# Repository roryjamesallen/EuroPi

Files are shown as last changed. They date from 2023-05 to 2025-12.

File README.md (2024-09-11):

# EuroPi

The EuroPi is a fully user reprogrammable module based on the [Raspberry Pi Pico](https://www.raspberrypi.com/products/raspberry-pi-pico/), which allows users to process inputs and controls to produce outputs based on code written in Python. The entire project is open-source.

<p>
  <a href="https://discord.gg/JaQwtCnBV5">
        chat on Discord
  </a>
  <a href="https://www.reddit.com/r/EuroPi/">
        
  </a>
  <a href="https://github.com/Allen-Synthesis/EuroPi/tree/main/software/contrib">
        
  </a>
  <a href="https://github.com/Allen-Synthesis/EuroPi/releases/">
        
  </a>

</p>

---

This repository relates to the EuroPi module, however some users may be expecting to see what is now referred to as the 'EuroPi Prototype'. The repository for this (now deprecated) module [can be found here](https://github.com/roryjamesallen/EuroPi-Prototype)

You can find more about this and other projects of mine on [my website](https://www.allensynthesis.co.uk)

github banner

## Capabilities

* 6 0-10V Control Voltage outputs, each with indicator LED
* 2 Knobs with 12 bit resolution
* 2 Push Buttons
* 1 0-12V Control Voltage input with 12 bit resolution
* 1 Digital input for external clocking or gate sources
* 128x32 OLED Display
* I²C expansion header on the rear for extra sensors or outputs

### Improvements on the Prototype version

* All outputs are the full Eurorack unipolar range of 0-10V, previously only 0-3.3V
* Two inputs, previously no way to accept input from other modules
* The buttons have hardware debouncing to allow users to change out capacitor values for reduced accidental 'double click'
* A 10 pin Eurorack shrouded power header is now used to prevent accidental reverse powering of the module
* The 5V supply for the Pico is now regulated down from the +12V supply, so no 5V rail is required from your Eurorack power supply
* The power supply is now diode protected to prevent back-powering your rack when the module is connected via USB
* All jacks are protected from overvoltage input (previously the Pico GPIO pin was directly exposed to any input, potentially leading to damage)

### Documentation

**Hardware**: Details of the hardware can be found at [hardware README](hardware/EuroPi/README.md). Additionally the [BoM](hardware/EuroPi/bill_of_materials.md) and the [build guide](hardware/EuroPi/build_guide.md) can be found in the hardware folder.

**Software**: Before using any of the software, follow the instructions in [programming_instructions.md](software/programming_instructions.md) to set up and calibrate your module.

A list of user contributed scripts and their usage can be found in [contrib/README.md](software/contrib/README.md).
There is also a [YouTube playlist](https://www.youtube.com/playlist?list=PLbingtr9KGPUdIODLWgzgAdIyN497YyEs) showcasing EuroPi and some of the different scripts available.

The EuroPi firmware API documentation can be found at https://allen-synthesis.github.io/EuroPi/. This documentation will explain all of the available features of the EuroPi firmware API. It also includes some examples of how to use various features of the firmware as well as [interesting_things.md](software/interesting_things.md).

If you would like to extend any of the features of the EuroPi software, you can view the firmware source code at [europi.py](software/firmware/europi.py).

### Issues
If you find any bugs, either in the software, the hardware, or the documentation, please create an Issue by clicking the 'Issue' tab along the top.
Please feel free to create any issue you see fit, I'll either attempt to fix it or explain it.
There are Issue templates available, so please choose whichever is most relevant, depending on if your Issue is a hardware or software bug, if it's a documentation error or suggestion, if it's a question about the project as a whole, or a suggestion about the project as a whole.

### License

This module, and any documentation included in this repository, is entirely "free" software and hardware, under different licenses depending on the software, hardware, and documentation itself.

* Software: [Apache 2.0](software/LICENSE)
* Hardware: [CERN OHL-S v2](hardware/LICENSE)
* Documentation: [CC0 1.0](LICENSE)

Anyone is welcome to design their own versions of the idea, or modify my designs.
The only thing I would ask is that you refrain from using the brand name 'Allen Synthesis' on your DIY builds if they have modified my files in any way, just to prevent any confusion if they end up being re-sold or distributed. This is in line with section 8.2 of the CERN license. You may use the brand name if you have simply copied the files from this repository to replicate without modification.

If you have a bug fix or improvement that you think is worth sharing, then feel free to send over any pictures or documentation and it can be merged with the main project!

### Disclaimer

Recreate any of the files found in this repository at your own risk; I will attempt to solve any issues that you might have with my designs, but I can't guarantee that there are not minor bugs in any of the documents, both hardware and software.

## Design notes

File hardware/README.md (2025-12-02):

# Hardware Overview
There are multiple versions of the hardware documented in this directory, the original EuroPi (through-hole), the new EuroPi-SMD (surface-mount), and a stripboard version (stripboard). Each has a different build guide and bill of materials, so make sure you follow the one you want to build.

The surface-mount version is the simplest to DIY as you only need to solder on the components which stick through the panel, i.e. the jacks, knobs etc. All of the other circuitry is soldered onto the PCB already.

The through-hole version is slightly more in depth as you need to solder on every component, however only through-hole components are used, so this isn't as hard as it sounds. This is the build most people have made and was previously the only publicly available build at all.

The stripboard version is a much rougher layout and does not use a PCB at all, but instead uses 'stripboard'. This hasn't been tested nearly as much as the other two, but people have successfully built it and shared their version on Discord.

# Hardware Specifications
All hardware variants share the same specifications as the components and schematics are the same.

## Outputs
- 1k Output Impedance
- RC filter smoothed PWM
- ~1.5kHz Maximum usable frequency (without changing RC values)
- 0.000176V Maximum ripple peak-to-peak
- 0.0108s Settle time from 0% to 90% duty cycle
- 0-10V

## Analogue Input
- 100k Input Impedance
- 0-12V Readable Range
- Protected for ±36V (TL074 limits, MCP6002 will always clip to ±3.3V)

## Digital Input
- 100k Input Impedance
- 0.8V threshold to read as high

## OLED
- SSD1306 0.91"
- 128 x 32 pixels
- I2C Protocol

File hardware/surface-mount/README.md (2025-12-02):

# EuroPi (surface-mount)

This is a version of the EuroPi that has all of the components other than the Pico, power header, and panel components pre-soldered using SMD packages. This makes for a much simpler DIY build, as well as a thinner end result. It has identical technical specifications to the through-hole version except for also supporting input detection.

The board files for this version are designed in [KiCad](https://www.kicad.org/) so are a more friendly starting point for third-party development or modification.

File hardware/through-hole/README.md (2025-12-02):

# EuroPi (through-hole)
This directory contains the build instructions and production files for the 'original' EuroPi, which is the entirely through-hole build. This is the build the majority of users have.

# PCB Files

The PCB files are in two file types:
- .pcb files, which can be opened in [DesignSpark](https://www.rs-online.com/designspark/pcb-software) free PCB software
- .rar files, which are zipped folders containing the Gerber format PCBs. Each entire .rar folder can be dragged and dropped to a PCB manufacturer such as [JLC PCB](https://jlcpcb.com/) (my personal choice)

There are two different options for the panel PCB:
- Panel, which is made for JLC aluminium production
- Black Panel, which is made for FR4 production by any manufacturer
The subtleties of these files are minor, but JLC will only produce the aluminium boards correctly if the layers are in the order that they are in these files, which is silkscreen on the bottom layer and copper on the top.

In line with the license used for the PCBs, if you modify these files before production (rather than just dragging and dropping the gerber files), please contact me if you would like to keep the 'Allen Synthesis' name on it! This is not based in any mistrust of your modifications, but in the risk that someone else might then get hold of these boards or files, turn to me for support, and be disappointed.

If you would rather save yourself the effort of ordering boards (and potentially paying import charges), you can also order Panel + PCB kits directly from me, which will ship with a lower lead time than a PCB manufacturer too!
https://allensynthesis.square.site/

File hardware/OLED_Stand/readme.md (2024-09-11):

# 3D printed OLED stands

A simple small stand for your OLED display. This helps hold it in place while soldering and keeps it snug against the face of the module.

> There are two versions of the stand, one for the CPC style OLED and one for the TPH (the Pi Hut) style OLED.

## CPC style OLED

3D print the file [OLED_Stand.stl](OLED_Stand.stl).

Put the stand on something about 5-10mm tall, then solder some component cutoff wire to your OLED so that they fall below the bottom of the stand. Place on your interface board, solder pins to board. Pins may need to be bent slightly for the model of OLED that you're using. Just align the stand and the display and you should be right in the middle of the cutout.

Print upside down for best results/least amount of supports. Should print very quickly on most printers. It takes 30 minutes on an Ender3 Pro.

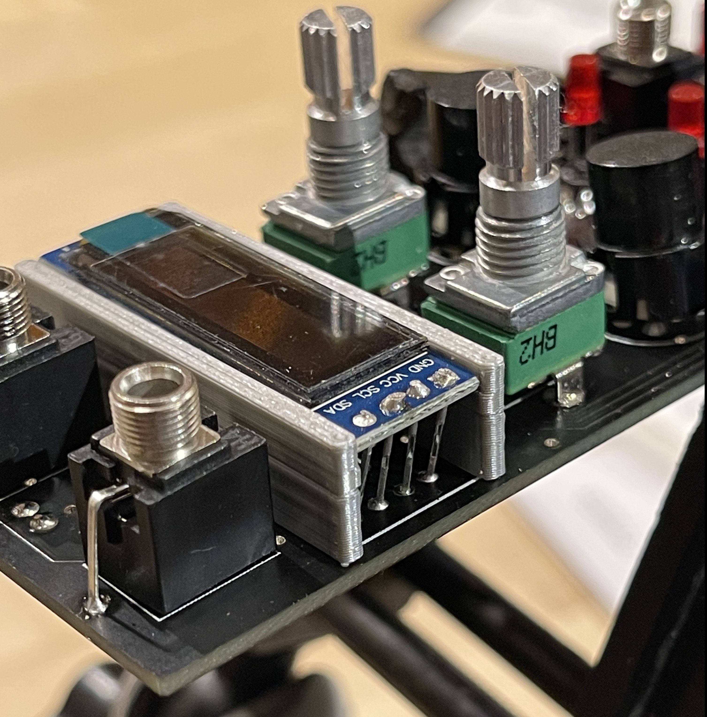
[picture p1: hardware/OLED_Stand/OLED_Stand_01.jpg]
OLED Stand
 

## TPH (the Pi Hut) style OLED

3D print the file [OLED_Stand_Pi_Hut.stl](OLED_Stand_Pi_Hut.stl).

The TPH (the Pi Hut) OLED needs a different stand because it has a chunky connector on the side (unused by the EuroPi).

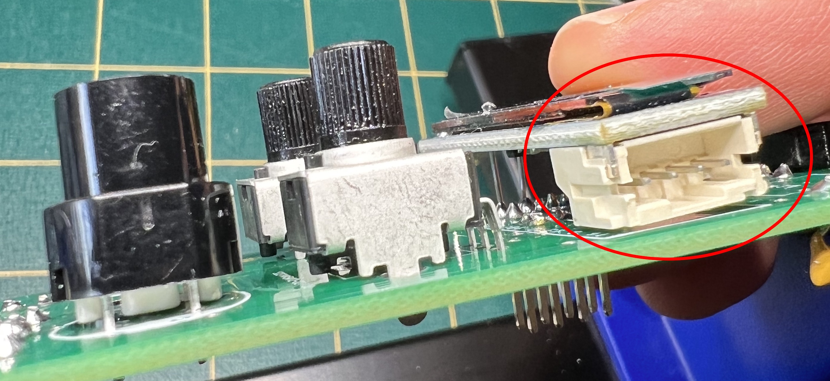
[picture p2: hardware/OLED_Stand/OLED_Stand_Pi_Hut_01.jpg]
OLED Pi Hut style
 

- Slide your OLED into the groove.
- Place the stand with OLED into position on the PCB (hold in place using bluetack).
- Solder the four vertical wires.

The stand has a notch to avoid certain soldering points. You should keep the stand permanently in your EuroPi for added stability of the screen.

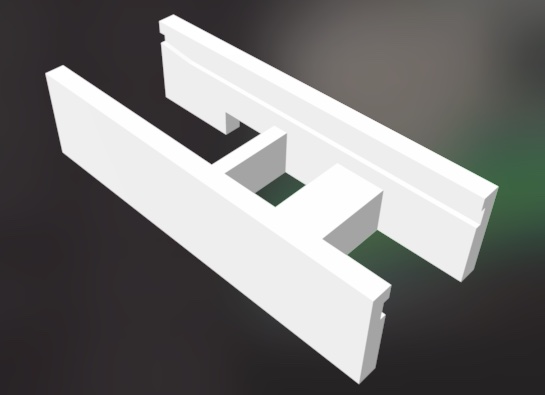
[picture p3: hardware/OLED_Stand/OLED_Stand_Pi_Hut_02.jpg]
OLED Stand for Pi Hut style


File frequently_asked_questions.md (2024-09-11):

# FAQ

### Frequently asked questions about the EuroPi project. If you can't find the answer to your question here, head over to [The Discord](https://discord.gg/JaQwtCnBV5) and ask it in the support channel!

#

### Topics:

### [General Questions](#general-questions)
### [Hardware Decisions](#hardware-decisions)
### [Bill of Materials (BOM)](#bill-of-materials)
### [Git](#git)
### [Programming](#programming-1)
### [Calibration](#calibration-1)

#

## General Questions

| Can the EuroPi process audio? | Some audio has been achieved on the EuroPi, such as t-schreibs' [Poly Square](software/contrib/poly_square.md) script, however full audio processing would likely require extra hardware to be accurate |
|--|--|

## Hardware Decisions

| Why did you use potentiometers and not encoders? | This module is designed to be a platform with which you can design fully functioning modules of your own, rather than a deep menu based system, and I feel that using encoders would encourage user interfaces that stray into the unusable. Users can always add encoders using i²c if they're determined! |
|--|--|

## Bill of Materials

| Do any of the capacitors need to be polarised? | No, non-polarised will work fine |
|--|--|

## Git/GitHub

| What is a 'Pull Request'? | This is a request made by a user to the main repository to 'pull' the extra data, either changes, new files, or deletions, from their fork into the main one. Essentially it is the way that users contribute to the main repository. The guidelines for creating a PR, and more explanation of what one is, can be found in the [contributing guidelines](contributing.md) |
|--|--|

## Programming

| Do I need to learn programming to use this module? | Nope! The menu system can be used with absolutely no programming knowledge at all, but once installed you are always free to write your own scripts if you feel like it |
|--|--|

## Calibration

NOTE: ADD THIS TO THE TROUBLESHOOTING GUIDE
| When in the second stage of calibration, my module never reaches 10V, what do I do? | Refer to the [troubleshooting guide](troubleshooting.md) |
|--|--|

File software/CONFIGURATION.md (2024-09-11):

# Configuration Customization

Certain properties of the module, such as screen rotation, CPU clock speed, and Raspberry Pi Pico model, can be
set using a static configuration file.  This file is located at `/config/EuroPiConfig.json` on the
Raspberry Pi Pico. If this file does not exist, default settings will be loaded.  The following shows the
default configuration:
```json
{
    "EUROPI_MODEL": "europi",
    "PICO_MODEL": "pico",
    "CPU_FREQ": 250000000,
    "ROTATE_DISPLAY": false,
    "DISPLAY_WIDTH": 128,
    "DISPLAY_HEIGHT": 32,
    "DISPLAY_SDA": 0,
    "DISPLAY_SCL": 1,
    "DISPLAY_CHANNEL": 0,
    "MAX_OUTPUT_VOLTAGE": 10,
    "MAX_INPUT_VOLTAGE": 12,
    "GATE_VOLTAGE": 5,
    "MENU_AFTER_POWER_ON": false
}
```

- `EUROPI_MODEL` specifies the type of EuroPi module. Currently only `"europi"` is supported. Default: `"europi"`
- `PICO_MODEL` must be one of `"pico"` or `"pico w"`. Default: `"pico"`
- `CPU_FREQ` must be one of `250000000` or `125000000`. Default: `"250000000"`
- `ROTATE_DISPLAY` must be one of `false` or `true`. Default: `false`
- `DISPLAY_WIDTH` is the width of the screen in pixels. The standard EuroPi screen is 128 pixels wide. Default: `128`
- `DISPLAY_HEIGHT` is the height of the screen in pixels. The standard EuroPi screen is 32 pixels tall. Default: `32`
- `DISPLAY_SDA` is the I²C SDA pin used for the display. Only SDA capable pins can be selected. Default: `0`
- `DISPLAY_SCL` is the I²C SCL pin used for the display. Only SCL capable pins can be selected. Default: `1`
- `DISPLAY_CHANNEL` is the I²C channel used for the display, either 0 or 1. Default: `0`
- `MAX_OUTPUT_VOLTAGE` is an integer in the range `[0, 10]` indicating the maximum voltage CV output can generate. Default: `10`
  The hardware is capable of 10V maximum
- `MAX_INPUT_VOLTAGE` is an integer in the range `[0, 12]` indicating the maximum allowed voltage into the `ain` jack.
  The hardware is capable of 12V maximum. Default: `12`
- `GATE_VOLTAGE` is an integer in the range `[0, 10]` indicating the voltage that an output will produce when `cvx.on()`
  is called. This value must not be higher than `MAX_OUTPUT_VOLTAGE`. Default: `5`
- `MENU_AFTER_POWER_ON` is a boolean indicating whether or not the module should always return to the main menu when
  it powers on.  By default the EuroPi will re-launch the last-used program instead of returning to the main menu. Default: `false`

# Experimental configuration

Other configuration properties are used by [experimental features](/software/firmware/experimental/__init__.py)
and can be set using a similar static configuration file. This file is located at `/config/ExperimentalConfig.json`
on the Raspberry Pi Pico. If this file does not exist, default settings will be loaded.  The following
shows the default configuration:

```json
{
    "VOLTS_PER_OCTAVE": 1.0,
}
```

- `VOLTS_PER_OCTAVE` must be one of `1.0` (Eurorack standard) or `1.2` (Buchla standard). Default: `1.0`

# Accessing config members in Python code

The firmware converts the JSON file into a `ConfigSettings` object, where the JSON keys are converted
to Python attributes.  The JSON object's keys must follow these rules, otherwise a `ValueError` will be raised:

1. The string may not be empty
1. The string may only contain letters, numbers, and the underscore (`_`) character
1. The string may not begin with a number
1. The string should be in `ALL_CAPS`

The JSON key is converted into a Python attribute of the configuration object. For example, this JSON file
```json
{
  "CLOCK_MULTIPLIER": 4,
  "HARD_SYNC": true,
  "WAVE_SHAPE": "sine"
}
```
would produce a Python object with these attributes:
```python
>>> dir(config_object)
[
  '__class__',
  '__init__',
  '__module__',
  '__qualname__',
  '__dict__',
  'to_attr_name',
  'CLOCK_MULTIPLIER',
  'HARD_SYNC',
  'WAVE_SHAPE'
]

>>> config_object.CLOCK_MULTIPLIER
4

>>> config_object.HARD_SYNC
True

>>> config_object.WAVE_SHAPE
'sine'
```

`europi.py` contains objects called `europi_config` and `experimental_config` which implement the core & experimental
customizations described in the sections above. Below is a detailed summary of the contents of these objects:

```python
>>> from europi import europi_config
>>> dir(europi_config)
[
  '__class__',
  '__init__',
  '__module__',
  '__qualname__',
  '__dict__',
  'to_attr_name',
  'CPU_FREQ',
  'DISPLAY_CHANNEL',
  'DISPLAY_HEIGHT',
  'DISPLAY_SCL',
  'DISPLAY_SDA',
  'DISPLAY_WIDTH',
  'EUROPI_MODEL',
  'GATE_VOLTAGE',
  'MAX_INPUT_VOLTAGE',
  'MAX_OUTPUT_VOLTAGE',
  'MENU_AFTER_POWER_ON',
  'PICO_MODEL',
  'ROTATE_DISPLAY'
]
```

When you import `europi` into your project you can access the `europi_config` object like this:
```python
from europi import *

# A voltage range we can select from in a user menu
VOLTAGE_RANGE = range(0, europi_config.MAX_OUTPUT_VOLTAGE)
```

Alternatively, you can access it using the fully qualified namespace:
```python
import europi

# A voltage range we can select from in a user menu
VOLTAGE_RANGE = range(0, europi.europi_config.MAX_OUTPUT_VOLTAGE)
```

# Note on Booleans

Python uses `True` and `False` to represent boolean values (starting with upper-case letters), but JSON uses `true` and
`false` (starting with lower-case letters).

This is an unavoidable inconsistency between the configuration file and the Python source code. When modifying the JSON
file to modify your configuration, make sure to use correct JSON boolean names, not Python names.

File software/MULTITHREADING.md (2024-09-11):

# Multi-Threading

The Raspberry Pi Pico used in EuroPi has 2 CPU cores.  By default only one core is used.  Micropython contains a
module called `_thread` that can be used to run code on both cores.  This can be helpful if, for example, your program
features a lot of mathematical calculations (e.g. floating point operations, trigonometry (e.g. `sin` or `cos`)) that
must be run quickly, but also features a complex GUI to render to the OLED.

## WARNING

Multi-threading is considered an experimental feature, and is intended for advanced programmers only. Adding threads to
your program can introduce many hard-to-debug errors and requires some understanding of some advanced topics not
covered here, including:
- thread safety
- concurrency
- semaphores & mutexes

Unless you're certain you need the additional processing power offered by the EuroPi CPU's second core, it is
_strongly_ recommended that you write your program using a single thread.

## Using `_thread`

To use the `_thread` library you must first import it into your program:
```python
import _thread
```

Your program will always contain at least one thread, referred to as the "main thread."  To start a second thread
you must define a function to execute and start it with `_thread.start_new_thread`:
```python
from europi import *
import time
import _thread

def my_second_thread():
    """The secondary thread; toggles CV2 on and off at 0.5Hz

    To allow the Python shell to connect when the USB is connected, we must terminate this thread
    when the USB state changes. Otherwise the secondary thread will continue running, blocking the shell
    """
    usb_connected_at_start = europi.usb_connected.value()
    while eurpi.usb_connected.value() == usb_connected_at_start:
        cv2.on()
        time.sleep(1)
        cv2.off()
        time.sleep(1)

def main():
    """The main thread; creates the secondary thread and then toggles CV1 at 1Hz

    This thread will automatically die if the USB is connected for debugging, so we don't
    need to check the USB state here.
    """

    # Start the second thread
    second_thread = _thread.start_new_thread(my_second_thread, ())

    while True:
        cv1.on()
        time.sleep(0.5)
        cv1.off()
        time.sleep(0.5)
```

This is a more complex example that implements the same logic as above, but wrapped in a `EuroPiScript`:
```python
from europi import *
from europi_script import EuroPiScript
import time
import _thread

class BasicThreadingDemo1(EuroPiScript):
    def __init__(self):
        super().__init__()

    def main_thread(self):
        """The main thread; toggles CV1 on and off at 1Hz
        """
        while True:
            cv1.on()
            time.sleep(0.5)
            cv1.off()
            time.sleep(0.5)

    def secondary_thread(self):
        """The secondary thread; toggles CV2 on and off at 0.5Hz
        """
        usb_connected_at_start = europi.usb_connected.value()
        while eurpi.usb_connected.value() == usb_connected_at_start:
            cv2.on()
            time.sleep(1)
            cv2.off()
            time.sleep(1)

    def main(self):
        # Clear the display
        oled.fill(0)
        oled.show()

        second_thread = _thread.start_new_thread(self.secondary_thread, ())
        self.main_thread()

if __name__ == "__main__":
    BasicThreadingDemo1().main()
```

## Best Practices

Because each thread runs on a different core, and the EuroPi's processor only has 2 cores, it is recommended to limit
your program to 2 thread: the main thread, and a single additional thread started with `_thread.start_new_thread`.

Interrupt Service Routines (ISRs), implemented as `handler` functions for button presses and `din` rising/falling edges
have been known to cause threaded programs to hang.  It is therefore recommended to _avoid_ using `handler` functions
in your program:
```python
# To NOT do this:
@b1.handler
def on_b1_rising():
    self.do_stuff()
```

Instead, [`experimental.thread`](/software/firmware/experimental/thread.py) provides a `DigitalInputHelper` class
that can be used inside your main thread to check the state of the buttons & `din` and invoke callback functions
when a rising or falling edge is detected.

For example:
```python
from europi import *
from europi_script import EuroPiScript

import time
import _thread

from experimental.thread import DigitalInputHelper

class BasicThreadingDemo2(EuroPiScript):
    def __init__(self):
        super().__init__()

        self.digital_input_helper = DigitalInputHelper(
            on_b1_rising = self.on_b1_press,
            on_b1_falling = self.on_b1_release,
            on_b2_rising = self.on_b2_press,
            on_b2_falling = self.on_b2_release,
            on_din_rising = self.on_din_high,
            on_din_falling = self.on_din_low
        )

    def on_b1_press(self):
        """Turn on CV4 when the button is held
        """
        cv4.on()

    def on_b1_release(self):
        """Turn off CV4 when the button is released
        """
        cv4.off()

    def on_b2_press(self):
        """Turn on CV5 when the button is held
        """
        cv5.on()

    def on_b2_release(self):
        """Turn off CV5 when the button is released
        """
        cv5.off()

    def on_din_high(self):
        """Turn on CV6 when the signal goes high
        """
        cv6.on()

    def on_din_low(self):
        """Turn off CV6 when the signal drops low
        """
        cv6.off()

    def main_thread(self):
        """The main thread; toggles CV1 on and off at 1Hz and handles the buttons + DIN
        """
        # calling time.sleep will block the input handling, so we need to check the clock instead
        last_state_change_time = time.ticks_ms()
        cv1_on = True
        cv1.on()

        while True:
            # Check the inputs
            self.digital_input_helper.update()

            now = time.ticks_ms()
            if time.ticks_diff(now, last_state_change_time) >= 500:
                last_state_change_time = now
                cv1_on = not cv1_on
                if cv1_on:
                    cv1.on()
                else:
                    cv1.off()

    def secondary_thread(self):
        """The secondary thread; toggles CV2 on and off at 0.5Hz
        """
        usb_connected_at_start = europi.usb_connected.value()
        while eurpi.usb_connected.value() == usb_connected_at_start:
            cv2.on()
            time.sleep(1)
            cv2.off()
            time.sleep(1)

    def main(self):
        # Clear the display
        oled.fill(0)
        oled.show()

        second_thread = _thread.start_new_thread(self.secondary_thread, ())
        self.main_thread()

if __name__ == "__main__":
    BasicThreadingDemo2().main()
```

One of the slowest operations in the EuroPi firmware is updated the OLED. If possible moving any GUI rendering into
a secondary thread is a good idea to optimize your program.  Note that you will likely need to use `Lock` objects
to prevent threads from trying to read/write data at the same time.

```python
from europi import *
from europi_script import EuroPiScript

import math
import _thread

class BasicThreadingDemo3(EuroPiScript):
    def __init__(self):
        super().__init__()

        # Create a lock object to prevent multiple threads from accessing our pixel array
        self.pixel_lock = _thread.allocate_lock()

        # Create an array that we'll store vertical pixel positions in to draw on screen
        self.pixel_heights = []

    def cv_thread(self):
        """The main thread; generates a sine wave on CV1
        """
        CYCLE_TICKS = 10000  # one complete sine wave every N times through the loop

        ticks = 0
        cv1_volts = 0
        while True:
            # convert the tick counter to radians for use with sin/cos
            theta = ticks / CYCLE_TICKS * (2*math.pi)

            # sin gives us [-1, 1], but we need to shift it to [0, MAX_OUTPUT_VOLTAGE]
            cv1_volts = (math.sin(theta) + 1) / 2 * MAX_OUTPUT_VOLTAGE

            # convert the voltage to an integer from 0 to OLED_HEIGHT
            # note that row 0 is the top, so we'll draw a line that goes down as the voltage goes up
            # since this is just an example, that's fine; the math to flip the visualization is left as
            # an exercise for the reader
            with self.pixel_lock:
                self.pixel_heights.append(int(cv1_volts * OLED_HEIGHT / MAX_OUTPUT_VOLTAGE))

                # Restrict the number of pixel heights to match the width of the screen
                if len(self.pixel_heights) >= OLED_WIDTH:
                    self.pixel_heights.pop(0)

            ticks = ticks + 1
            if ticks >= CYCLE_TICKS:
                ticks = 0

            cv1.voltage(cv1_volts)

    def gui_thread(self):
        """Draw the wave shapes to the screen
        """
        usb_connected_at_start = europi.usb_connected.value()
        while eurpi.usb_connected.value() == usb_connected_at_start:
            # clear the screen
            oled.fill(0)

            # Draw the pixels representing our waves
            # Make sure to grab the lock so the arrays aren't modified while we're reading them!
            with self.pixel_lock:
                for i in range(len(self.pixel_heights)):
                    oled.pixel(i, self.pixel_heights[i], 0xff)  # draw a white pixel

            # Show the updated display
            oled.show()

    def main(self):
        second_thread = _thread.start_new_thread(self.gui_thread, ())
        self.cv_thread()

if __name__ == "__main__":
    BasicThreadingDemo3().main()
```

## Cancelling Execution and Thonny

If you use Thonny to debug your EuroPi programs, note that when you cancel execution with `ctrl+C` the second core
will likely still be busy. This can cause Thonny to raise errors when trying to e.g. run another function in the
Python terminal or saving files to the module.

If this happens, simply Stop/Restart the backend via Thonny's Run menu.

## References

- [Official Python `_thread` docs](https://docs.python.org/3/library/_thread.html)

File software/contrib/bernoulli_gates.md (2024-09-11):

# Bernoulli Gates

author: Bridgee

date: 03/13/22

labels: Random

### General
This app is based on Mutable Instruments Branches. Because EuroPi only have a pair of digital/analogue inputs, the dual Bernoulli gates share the same clock (from the digital input), and only one Bernoulli gate have CV input.

A Bernoulli gate takes a logic signal (trigger or gate) as an input, and routes it to either of its two outputs according to a random coin toss.

Knob 1 adjusts the probability of the Bernoulli gate 1, and Knob 2 adjusts the probability of the Bernoulli gate 2.

Button 1 switches the mode of gate 1 between trigger mode, toggle mode, and gate mode (latch mode), and Button 2 switches the mode of gate 2 between trigger mode, toggle mode, and gate mode (latch mode).

### Tigger mode (Tr)

When the **trigger mode** is enabled, an output A/B changes to +5V for 10ms every time they are activated by the corresponding Bernoulli gate.

### Gate mode/Latch mode (G)

When the **gate mode** is enabled, an output A/B stays at +5V until the other output gets activated.

### Toggle mode (Tg)

In **toggle mode**, the module associates the “heads” and “tails” outcomes to a different pair of decisions: “continue sending the trigger to the same output as before” and “send the trigger to the opposite output”. As a result, when the probability knob 1 is set to its maximum value, the trigger will alternate between outputs A and B.

    digital in: trigger/clock
    analogue in: probability control of gate 1 (summed with Knob 1)
    knob 1: probability control of gate 1
    knob 2: probability control of gate 2
    button 1: mode switch of gate 1
    button 2: mode switch of gate 2
    cv1/cv2: output A/B of gate 1
    cv4/cv5: output A/B of gate 2
    cv3: copy of trigger/clock
    cv6: logic AND of the two output A

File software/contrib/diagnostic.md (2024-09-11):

# Diagnostic

author: Matthew Jaskula

date: 2022-01-19

labels: utility

A diagnostic utility intended to help prove out a new EuroPi build and calibration. Each aspect of the EuroPi's hardware
is exercised.

- Input values, including knobs and buttons, are shown on the screen.
- Outputs are held at specific, predictable, and hopefully useful values.
- each button press rotates the voltages amongst the six outputs, which helps to test the LEDs.
- Inputs can be tested by self-patching the various CV outputs.
- The boundary of the screen is outlined.
- Temperature, as read by the Pico's onboard temperature sensor, is shown on screen; in degrees fahrenheit when a button
    is pressed and degrees celsius otherwise.

Inputs and Outputs:
- **digital in:** value displayed on screen
- **analog in:** value displayed on screen
- **button 1:** rotate output voltages backwards
- **button 2:** rotate output voltages forwards
- **knob 1:** value 0-99 displayed on screen
- **knob 2:** value 0-99 displayed on screen
- **cv X:** output a constant voltage, one of [0, 0.5, 1, 2.5, 5, 10]

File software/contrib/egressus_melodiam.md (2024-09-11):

# Egressus Melodiam (Stepped Melody)

author: Nik Ansell (github.com/gamecat69)
date: 19-Feb-24
labels: clocked lfo, sequencer, CV, randomness
Demo Video: https://youtu.be/_qlnV_ewb_c

Clock-able and free-running LFO and random CV pattern generator.
Eight different wave shapes either define the LFO shape or the slew shape between CV pattern steps.
Use it to generate variable length melodies (using a quantizer), LFOs or weird and wonderful control voltages.   

# Inputs, Outputs and Controls

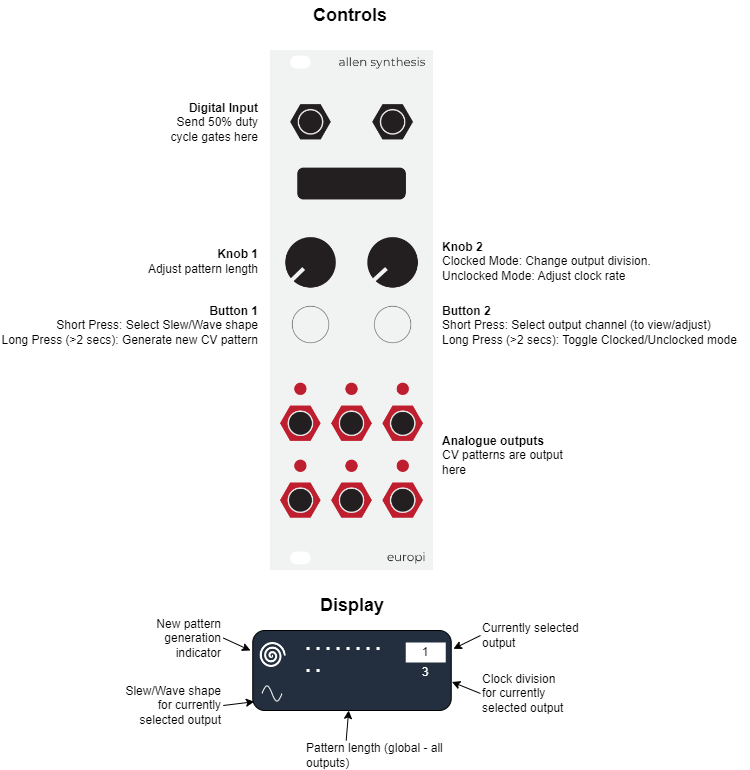
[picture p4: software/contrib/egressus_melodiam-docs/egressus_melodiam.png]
Operating Diagram


Analogue outputs send a voltage from 0V to the maximum configured output voltage (MAX_OUTPUT_VOLTAGE) as defined by europi_config.
The default maximum output voltage is +10V.

# Getting started

1. Patch a 50% duty cycle square wave or clock with pulses >= 16ms in duration into the digital input
2. Connect one or more outputs to an input on another module (e.g. CV modulation inputs)
3. Select a pattern length using Knob 1
4. Start your clock. Each output will now send a looping CV pattern to your module!

So, what happened in the above example?
When the module first powered on it automatically generated 6 x 32 step random CV patterns - one for each of the 6 outputs.
Each time a clock is received, the step advances by one step and then loops when it get to the end of the pattern.
The length of the pattern loop is controlled using knob 1, which supports a value from 1 to 32.

# Changing the slew/wave shape and clock division of an output

Refer to the above diagram for a visual representation of the example below.

1. Press and release button 2 until the output number you would like to edit is shown on the top-right.
2. Press button 1 to cycle through the available wave shapes
3. Adjust knob 2 to select the output division. An output division of 1 causes the CV pattern / LFO for that
output to run at the clock rate. An output division greater than one reduces the CV pattern / LFO to run at the selected division (e.g. selecting a division of 2 would run at half the clock rate)

In LFO mode (pattern length of 1) the wave shape determines the shape of the cycling LFO. However, when in CV pattern mode (Pattern length > 1) the wave shape determines the slew between pattern steps.

## Available Slew/wave shapes

Eight shapes are available. Some are symmetrical where the rising shape is the same as the falling shape, others are asymmetrical.

- [](square.png) **Square/Step**: Moves up/down immediately and holds until the next step
- [](tri.png) **Triangle/Linear**: A straight line between steps
- [](sine.png) **Sine/Smooth**: A smooth line between steps using a sine/cosine wave
- [](exp-up-exp-down.png) **Exponential up and down**: An exponential curve between steps. This rises/falls slowly at the start and fast at the end
- [](sharktooth.png) **Sharktooth**: Logarithmic rise, exponential fall. A logarithmic curve rises/falls quickly at the start and slowly at the end.
- [](sharktooth-rev.png) **Reverse Sharktooth**: Exponential rise, Logarithmic fall.
- [](log-up-step-down.png) **Logarithmic up, step down**: Upward transitions are logarithmic, downward transitions are stepped.
- [](square-up-exp-down.png) **Step up, exponential down**: Upward transitions are stepped, downward transitions are exponential.

# Generating a new CV pattern for an output

A new CV pattern is generated for the selected output by holding down button 1 for 2 seconds and releasing. An indicator is shown on the top left of the screen to show a new CV pattern has been generated. Note that if you are in LFO mode (pattern length of 1) this function will have no effect until the pattern length is increased. 

# LFO Mode / CV Pattern mode

Selecting a pattern length of 1 will output an LFO.
Selecting a pattern length greater than one plays through the generated CV patterns.
Slew is generated between CV pattern steps when a wave shape other then square is selected.

# Clocked / Free-running mode

Clocked mode is selected by default - indicated by showing the length of the CV pattern (in dots) in the middle of the screen.
To enter free-running mode, hold button 2 for 2 seconds and release. The configured clock rate in milliseconds is shown
in the middle of the screen to indicate you are in free-running mode.

Note that when in free-running mode, the previously selected pattern length remains unchanged, it is therefore a good idea to select the required pattern length before changing to unclocked mode.

# Saving and loading

All settings and CV patterns are saved when changes are made and will not be lost when the module is powered off.

# Changing the maximum CV voltage

CV Patterns (including LFOs) output a range of 0-10V based on the default globally configured value.
If you would like to change this value, two methods are available 1) Create a json file (see below), 2) Configure the global configuration value using the UI (coming soon in a later firmware release).

## Reducing the maximum CV output using a json file

1. Create a file on your pico named `config/config_EuroPiConfig.json`. Thonny is the easiest method for this.
2. Add the following to the json file:

```json
{
    "max_output_voltage": 5
}
```

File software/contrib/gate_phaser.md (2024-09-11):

# Gate Phaser

author: Nik Ansell (github.com/gamecat69)

date: May 2024

labels: sequencer, gates

A script which attempts to answer the question "What would Steve Reich do if he had a EuroPi?".

Gates are sent from outputs 1-6 which are offset (or out of phase) with each other. This creates a group of gates that drift in and out of phase with each other over time.

You can use this script to create Piano Phase type patches, dynamic rhythms which evolve over time and eventually resolve back in phase, or ... well lots of other things that would benefit from having gates which are delayed from each other.

# Inputs, Outputs and Controls

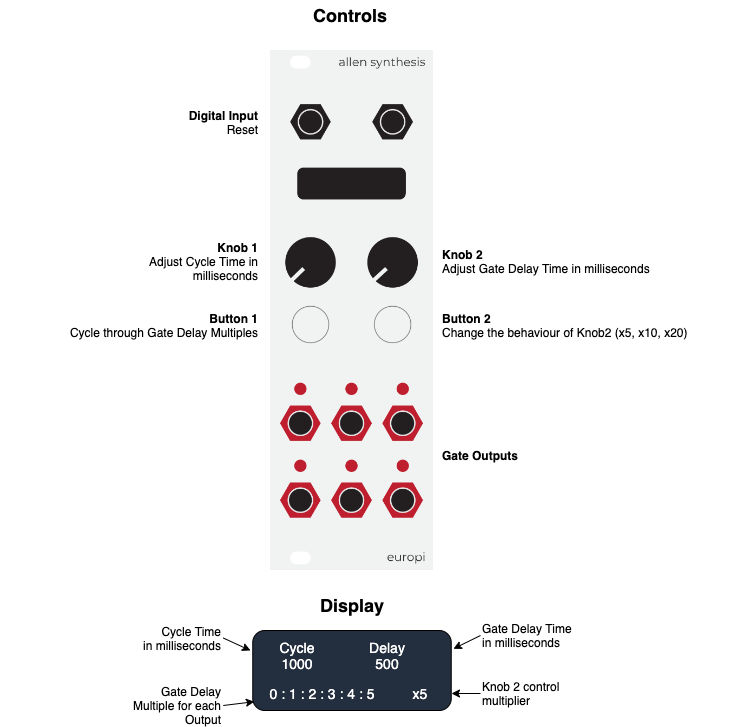
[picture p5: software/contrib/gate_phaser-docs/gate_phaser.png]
Operating Diagram

  
# Getting started

1. Patch anything you want to trigger with a gate to any of the outputs, for example
percussions elements, emvelopes, sequencer clocks or samples.
2. Set the Cycle time in milliseconds using knob 1
3. Set delay time in milliseconds using knob 2
4. Set the desired gate delay interval using button 1
5. Use button 2 to change the behaviour of knob 2 to set the desired gate delay time

# So what is this script actually doing?

**Cycle time** is the time in milliseconds between gate outputs at output 1 when the gate delay multiple for output 1 is set to 0.

**Gate delay** is the time in milliseconds that gate outputs are delayed from the master cycle time.

**Gate multiples** are multiples of the gate delay time per output.

## For Example:

- Cycle Time: 1000ms
- Gate Delay Time: 500ms
- Gate Delay Multiples: 0:1:2:3:4:5

The initial output is sent after "Gate Delay Time * Gate Delay Multiple" milliseconds.
Each subsequent output is sent after "Cycle Time + (Delay Time * Gate Delay Multiple)" milliseconds.

Therefore after the initial gate output from each output:

- Output 1 sends a gate every 1000ms 
- Output 2 sends a gate every 1500ms
- Output 3 sends a gate every 2000ms
- Output 4 sends a gate every 2500ms
- Output 5 sends a gate every 3000ms
- Output 6 sends a gate every 3500ms

Which results in the following:

| Output | t0 | 500ms | 1000ms  | 1500ms  | 2000ms  | 2500ms  | 3000ms  | 3500ms  | 4000ms  |
|---|---|---|---|---|---|---|---|---|---|
| 1 | x | | x | | x | | x | | x |
| 2 | | x | | | x | | | x | |
| 3 | | | x | | | | x | | |
| 4 | | | | x | | | | | x |
| 5 | | | | | x | | | | |
| 6 | | | | | | x | | | |

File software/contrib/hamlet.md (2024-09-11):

# EuroPi Hamlet - Sequencing Drums and Two Voices

author: Sean Bechhofer (github.com/seanbechhofer)

date: 2022-04-16

labels: sequencer, gates, triggers, drums, randomness

**TB or not TB?**

Hamlet is a drum and voice sequencer based on Nik Ansell's
Consequencer, which is itself inspired by Grids from Mutable
Instruments. It's also influenced by O_C's TB3PO. Hamlet adds two
tracks of CV and gates to the Consequencer, sacrificing one drum track
to do so.

The app provides two gates for drum patterns and a pair of channels
giving gate/CV to drive voices. Density of notes played on the CV
tracks can be adjusted.

Use outputs 1/2 for drum gates. Pairs 3/4 and 5/6 provide gate/CV for
melody lines. Send a clock to the digital input to start the sequence.

Demo video: https://www.youtube.com/watch?v=bEbHBpgIl4A

Credits:
- The Europi hardware and firmware was designed by Allen Synthesis:
https://github.com/Allen-Synthesis/EuroPi
- Hamlet is based on the Consequencer by Nik Ansell (github.com/gamecat69)

# Controls

hamlet_controls

- digital_in: Clock in
- analog_in: Mode 1: Randomness, Mode 2: Selects gate pattern, Mode 3: Selects voice patterns

- knob_1: Adjust sparsity
- knob_2: Select pre-loaded gate pattern

- button_1: Short Press: Select previous voice pattern for tracks 1 and 2.
  Long Press: Cycle pattern length multiplier
- button_2: Short Press: Select next voice patterns for tracks 1
  and 2. Creates a new pattern if we're at the last.
  Long Press: Cycle through analogue input modes

- output_1: gate 1 e.g Kick Drum
- output_2: gate 2 e.g Hi-Hat
- output_3: track 1 gate
- output_4: track 2 gate
- output_5: track 2 randomly generated stepped CV
- output_6: track 1 randomly generated stepped CV

# Getting Started

The following sections provide instructions for creating a simple 2
drum pattern with a kick and hi-hat, then using random CV patterns to
drive voices.

## Basic Usage
1. Connect a clock input to the Digital input
2. Connect a Bass Drum to output 1, Hi-hat to output 2
3. Start your clock - the pattern will output gates on outputs 1/2.
4. Select different patterns manually using knob 2 (right-hand
knob). The first section of the selected gate pattern for track 1 is shown visually on the screen.

## Voices
1. Connect output 3 to gate on voice 1
2. Connect output 6 to pitch on voice 1, optionally via quantiser/attenuator.
3. Connect output 4 to gate on voice 2
4. Connect output 5 to pitch on voice 2, optionally via quantiser/attenuator.
5. Gates will be output on 3/4 according to the gate pattern
6. The gate pattern for track 1 will be shown on the screen.
7. Knob 1 increases or decreases the sparsity of the gates sent to
   outputs 3 and 4. Fully CCW all notes are played, as the knob is
   turned CW, notes will drop out of the sequence.

## Sparsity

A key feature of the two voice tracks in Hamlet is *sparsity*
control. With this set to 0, all events in the track are present. As
the level of sparsity increases, the number of gates emitted
reduces. The CV output values will only change when a gate is
emitted.

This is done as follows. Each track has a number of steps, each with a
voltage and sparsity value: here we assume 16 as this is a common
pattern length. Sparsities are allocated randomly from 1 to the length
of the track. When the value selected by the left knob is greater than
the sparsity value, the step is disabled, and no change to CV value is
made. The figure below shows this, with values `V1` up to `V16` being
the voltages in the pattern and the sparsity values shown in the
second row. As the knob value increases, more gates are
disabled. Here, `VX` refers to the CV value that was being emitted
before the pattern started. For example, if the knob sparsity is 10
and the pattern is looping, then `VX` will be `V16`.

hamlet-sparsity

Note that every time a CV pattern is created through a right button
press, that pattern will have a new random set of sparsity
values. Note also that track 1 and track 2 have *different* gate
patterns, thus different notes will drop out giving some nice
interplay between the voices.

## Pattern Length

CV patterns are N, 2xN or 4xN steps, where N is the length of the
current drum pattern. This can be varied through a long
press on Button 1, and the display will indicate `1x`, `2x` or `4x`
respectively. Patterns of length 2xN and 4xN will be made up of two or four
(different) N step patterns as described above. So when sparsity is
set to `15` with pattern length `4x`, there will be four notes played
across the 64 note sequence.

## Selecting analogue input modes

Hamlet can perform 3 different actions when a control voltage input is received at the analogue input.
The current running mode is shown on the bottom right of the screen (e.g. M1, M2, M3)
Cycle through the modes by long-pressing and releasing button 2. The following modes are available:

- Mode 1: Randomness
- Mode 2: Control voltage selects the gate pattern
- Mode 3: Control voltage selects the stepped CV pattern

## Controlling a pattern using CV

1. Select analogue mode 2.
2. Send a control voltage into the analogue input

A fixed voltage will select a single pattern and varying voltage (e.g. an envelope or LFO) will smoothly cycle through patterns.

## Adding / Removing / Updating Gate Patterns

1. Update patterns in the code
2. Restart the Europi module, or restart the program if using a micropython IDE/CLI

The syntax is like Consequencer, but with only two tracks.

The mapping of `BD`, `HH` is as follows:
- BD: Output 1
- HH: Output 2

```
    BD.append("1000100010001000")
    HH.append("1111111111111111")
```

# Known bugs / Interesting features

Probably.

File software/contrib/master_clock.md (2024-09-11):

# EuroPi Master Clock and Clock Divider

'''
Master Clock
author: Nik Ansell (github.com/gamecat69)
date: 2022-08-02
labels: clock, divider

A master clock and clock divider. Each output sends a +5V trigger/gate at different divisions of the master clock, or randomly if condigured with a division of zero.
Pulse width (gate/trigger duration) is configurable up to a maximum of 50% of the pulse width of output 1.

All configuration (BPM, Pulse Width, output clock divisions) is automatically saved, then loaded when the module is restarted.

For wonky/more interesting clock patterns try these:
- Reset to step 1 using a gate into the digital input, or by using an odd value for the maximum division
- Vary BPM by sending CV into the analog input
- Set the division to zero for an output, this will cause the output to randomly go from high (+5V) to low (0V)

Demo video: TBC

knob_1: (in config mode) Select option to edit
knob_2: (in config mode) Edit selected option

knob_1: Screen 2: Adjust BPM. Screen 3: Select output to edit
knob_2: Screen 2: Adjust Pulse width. Screen 3: Adjust division of selected output

button_1: Short Press (<500ms): Start/Stop (when using internal clock). Long Press (>500ms): Select clock source (Internal/External)
button_2: Short Press (<500ms): Not used. Long Press (>500ms): Enter config mode

Defaults:
output_1: clock / 1
output_2: clock / 2
output_3: clock / 4
output_4: clock / 8
output_5: clock / 16
output_6: clock / 32

Known Issues:
- BPM occasionally drifts by 1ms - possibly because asyncio is is truely async

# Getting started

Patch any module that uses gates/triggers to any output! By default the module will run at 100 BPM, using a 50% pulse width and send gates using the default divisions (1,2,4,8,16,32).

# Configuring / Playing around

Hold button 2 for 2 seconds to enter configuration mode, then use knob 1 (left) to adjust BPM and knob 2 (right) to adjust pulse width. To exit configuration mode, just press button 2 to move to the next screen.

Playback may be slightly erraratic when in config mode - this is due to more screen updates hogging the CPU

## Screen

This screen shows the BPM, Pulse width and configured clock division for each output.
The Pulse width is displayed as `PW:MS`. `PW` is a percentage of the output 1 division and `MS` is the duration of each pulse in milliseconds

To edit the BPM (internal clock mode only), Pulse Width or the clock division for an output:
- Use knob 1 to select the output you want to edit
- Press and hold button 2 for 2 seconds to enter configuration mode
- Use knob 2 to select the division you want that that output.
- Exit configuration mode by holding button 2 for 2 seconds.

# Selecting a Clock Source

Master clock can generate its own clock, or use an external clock.
Enter clock source configuration mode using a long press on button 1.
Pressing either button 1 or button 2 will configure and save the clock source.

If using an external clock, patch the clock source into the din jack - the clock source should ideally send a gate/trigger longer than 9ms to avoid issues.

Note that when using an external clock, the reset functionality using the din jack is disabled.

# Randomizing pulses

Selecting a clock division of `/r` will cause pulses to be sent randomly from the configured output. Note that the 'r' option is at the end (far right) of the division options.

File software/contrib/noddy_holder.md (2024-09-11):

# Noddy Holder

author: Sean Bechhofer (github.com/seanbechhofer)
date: 2022-03-26
labels: gates, sample&hold, track&hold

*Cum On Feel the Noize!* Two channels of sample/track and hold based on
a single trigger and CV source.

Digital in is a gate, Analog in is arbitrary CV.

Output 1 is the original gate, Output 2 is S&H based on gate and CV,
Ouput 3 is T&H based on gate and CV.

Outputs 4, 5 and 6 are similar, but with the gate *inverted*.

Credits:
- The Europi hardware and firmware was designed by Allen Synthesis: https://github.com/Allen-Synthesis/EuroPi

# Controls

- digital_in: Gate
- analog_in: CV

- knob_1:
- knob_2:

- button_1:
- button_2:

- output_1: gate
- output_2: s&h based on gate
- output_3: t&h based on gate
- output_4: inverted gate
- output_5: s&h based on inverted gate
- output_6: t&h based on inverted gate

## Basic Usage
1. Switch on
2. Connect outputs to modules
3. Send gate and CV to inputs
4. Send resulting gates and CV to modules

## Controls
1. There are no controls. Noddy doesn't listen to The Man.

## Details

*Sample & Hold:* When gate goes ```HIGH```, CV is sampled, and the resulting value is
output until the gate goes ```HIGH``` again and we re-sample.

*Track & Hold:* When gate is ```HIGH```, CV input is mirrored to the
output. When gate goes ```LOW```, CV is sampled and the resulting value is
output until the gate goes ```HIGH``` again.

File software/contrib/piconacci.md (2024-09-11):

# EuroPi Piconacci - Fibonacci based triggers

author: Sean Bechhofer (github.com/seanbechhofer)

date: 2022-05-165

labels: triggers, numbers

Piconacci is a simple trigger generator that produces a collection of triggers, one of each of the six outputs. Each output is associated with a clock division value. Those values are drawn from the Fibonacci series. So for example, clock divisions of 1, 2, 3, 5, 8, and 13.

Short button presses will move the trigger values through the sequence, e.g. to 2, 3, 5, 8, 13, and 21.

Long button presses will rotate the values, e.g. to 3, 5, 8, 13, 21, and 2.

Credits:
- The Europi hardware and firmware was designed by Allen Synthesis:
https://github.com/Allen-Synthesis/EuroPi
- The name was suggested by @djmjr on the EuroPi Discord.

# Controls

- digital_in: Clock in
- analog_in: Not used
- knob_1: Not used
- knob_2: Not used

- button_1: Short Press: move left in Fibonacci sequence
  Long Press: Rotate triggers
- button_2: Short Press: move right in Fibonacci sequence
  Long Press: Rotate triggers

- output_1: trigger
- output_2: trigger
- output_3: trigger
- output_4: trigger
- output_5: trigger
- output_6: trigger

## Basic Usage
1. Connect a clock input to the Digital input
2. Triggers will appear on the outputs.
3. Use buttons to move values or rotate the triggers.

# Details

Piconnaci emits triggers on each output with clock divisions based on
values from the Fibonacci series. Those values are taken by selecting
a "window" of six consecutive values and then assigning values to the
outputs. The window can be moved and rotated through short and long
button presses.

In the diagrams below, the green boxes indicate the values in the
Fibonacci series. The blue boxes indicate the active "window" with the
numbers showing which division is used for each output.

pico drawio

# Limitations

The code has a limit on the number of values used (50). In practice this is unlikely to be an issue and probably works for most sensible circumstances. The 50th value (disregarding 0, 1) is 20,365,011,074. At a BPM of 120, that'll be a trigger every 300 years which is pretty slow even for glacial ambient.

Trigger length is coupled to the incoming clock.

# Known bugs / Interesting features

Probably.

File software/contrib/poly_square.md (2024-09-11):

# Poly Square

author: Tyler Schreiber (github.com/t-schreibs)
date: 2022-05-10
labels: oscillator, poly

An oscillator? On the EuroPi? You bet!

This script makes use of a small PIO program to produce six square wave oscillators, each of which can be set to different frequencies. For a brief primer on the Pi Pico's PIO, visit https://blues.io/blog/raspberry-pi-pico-pio/. The core PIO program for this script had its origins in Ben Everard's great little article on HackSpace: https://hackspace.raspberrypi.com/articles/raspberry-pi-picos-pio-for-mere-mortals-part-3-sound. Is it all just assembly code magic? Yes, sort of, but it really isn't all that scary if you take the time to learn how the different PIO instructions work. There are only 9 of them!

The Poly Square is six independent oscillators which output on CVs 1-6. The base pitch is set by the analog input, which is interpreted as a V/oct input with 0V = C. Knob 1 allows for detuning of the 6 voices, and as the knob is turned clockwise, the spread between them increases. Button 2 toggles the maximum detune between a half step and a major 9th. Knob 2 sets the polyphony mode.

## The polyphony modes
The following is a table of all available polyphony modes, as well as the offset of each CV output from the root note (shown in half steps):
| Mode | CV1 | CV2 | CV3 | CV4 | CV5 | CV6 |
|---|:-:|:-:|:-:|:-:|:-:|:-:|
| Unison | 0 | 0 | 0 | 0 | 0 | 0 |
| 5th | 0 | 0 | 7 | 0 | 0 | 7 |
| Octave | 0 | 0 | 12 | 0 | 0 | 12 |
| Power chord | 0 | 7 | 12 | 0 | 7 | 12 |
| Stacked 5ths | 0 | 7 | 14 | 0 | 7 | 14 |
| Minor triad | 0 | 7 | 15 | 0 | 7 | 15 |
| Major triad | 0 | 7 | 16 | 0 | 7 | 16 |
| Diminished | 0 | 6 | 15 | 0 | 6 | 15 |
| Augmented | 0 | 8 | 16 | 0 | 8 | 16 |
| Major 6th | 0 | 4 | 9 | 0 | 4 | 9 |
| Major 7th | 0 | 4 | 11 | 0 | 4 | 11 |
| Minor 7th | 0 | 3 | 10 | 0 | 3 | 10 |
| Major penta. | 0 | 2 | 4 | 7 | 9 | 12 |
| Minor penta. | 0 | 2 | 3 | 7 | 9 | 12 |
| Whole tone | 0 | 2 | 4 | 6 | 8 | 10 |

## Tuning mode
When button 1 is depressed, tuning mode is activated, and it remains active until the button is released. While in tuning mode, the base pitch for a 0V signal may be adjusted. In tuning mode, knob 1 is repurposed to adjust coarse tuning (up to 8 octaves) while knob 2 handles fine tuning (up to an octave). Tuning settings are saved to storage when button 1 is released.

Credits:
- The Europi hardware and firmware was designed by Allen Synthesis: https://github.com/Allen-Synthesis/EuroPi
- The basis of the PIO code is from an example written by Ben Everard in a HackSpace article: https://hackspace.raspberrypi.com/articles/raspberry-pi-picos-pio-for-mere-mortals-part-3-sound
- Thanks to djmjr (github.com/djmjr) for testing that 6 oscillators can be run simultaneously, and for the idea to refrain from adjusting tuning settings until the knobs have been moved

# Controls
- digital_in: unused
- analog_in: V/oct
- knob_1: detune
- knob_2: polyphony mode
- button_1: while depressed, 'tuning mode' is turned on; this changes the knob functionality:
    - knob_1: coarse tune (up to 8 octaves)
    - knob_2: fine tune (up to an octave swing)
- button_2: toggles the maximum detune between a half step and a major 9th
- output_1: oscillator 1
- output_2: oscillator 2
- output_3: oscillator 3
- output_4: oscillator 4
- output_5: oscillator 5
- output_6: oscillator 6

## Basic Usage
1. Switch on
2. Connect outputs to mixer, filters, what have you
3. Send V/oct signal to analog input
4. Enjoy square waves

## Details
Polyphony modes are easy to add! Just add them to the PolySquare.modes list.

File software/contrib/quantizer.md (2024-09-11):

# Quantizer

An equal-temperment quantizer with a selection of scales.

For best results make sure your EuroPi is well-calibrated.

The quantizer can operate in two modes: triggered (default)
and continuous.

- `ain`: the analog input to be quantized
- `din`: when in triggered mode, the trigger to quantize is
  received on this input
- `cv1`: the quantized output
- `cv2-5`: the quantized output, shifted up or down a fixed
  number of semitones
- `cv6`: a trigger when the output note changes (in continuous
  mode) or a copy of the signal sent to `din` (in triggered mode)
- `button 1`: toggle note (on keyboard screen) or apply new
  setting (on menu screen)
- `button 2`: toggle between the keyboard & menu screens
- `knob 1`: cycle through the note to toggle (on keyboard
  screen) or the menu items (on menu screen)
- `knob 2`: cycle through available options for the current
  setting (on menu screen). Unused on keyboard screen

## Usage

Connect the signal to be quantized to the analog input.

If operating in triggered mode, connect a clock pulse,
square LFO, or other trigger source to the digital input.

When a trigger is received on the digital input, the analog input
will be quantized to the nearest note on the selected scale and
output out Output 1.

Outputs 2-5 output the same note as output 1, but can be shifted
up/down a fixed number of semitones.  This allows the EuroPi to
generate quantized voltages to produce chords across multiple
oscillators.

In continuous mode output 6 will output a trigger whenever the
output note changes.

In triggered mode output 6 will mirror the digital input.

## Menu Operation

To switch between the keyboard view and the advanced menu, press
button 2.

In keyboard view, use knob 1 to select and note and press
button 1 to enable/disable it.  Enabled notes are marked
with a small circle near the top of the keyboard.

In the menu view, use knob 1 to scroll through items.  Use
knob 2 to scroll through available options for the given
item.  To apply the selection, press button 1.

### Menu Items

- Mode: either continuous or triggered (see Usage, above)
- Transpose: used to transpose the output voltage up a set
  number of semitones. Note that the keyboard view will remain
  unchanged; only the output voltage(s) will be transposed
- Octave: used to shift the output voltage up or down a number
  of octaves.  Because the module cannot output negative
  voltages, if your auxilliary outputs are set to negative
  intervals they may be clipped to zero if the octave is not
  raised (-1 to +2).
- Output 2-5: set the interval between Output 1 and Output N.
  The interval can be any semitone between -1 octave and +1
  octave.  Note that if the input signal is less than 1 volt
  and the octave is set to 0, negative intervals may be
  clipped.

## Screensaver

After 20 minutes of idleness the screen on the EuroPi will go blank
to prevent burn-in.  It will continue to quantize inputs normally,
just without visual feedback.

To wake the screen back up, simply press either button once.

## Patch Idea

Connect outputs 2-5 to a sequential switch, with the output of
the switch going to an oscillator.  This way the interval
between one oscillator connected to output 1 and the second
connected to the sequential switch will change every time the
switch gets triggered.

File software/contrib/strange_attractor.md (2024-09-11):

# EuroPi Strange Attractor.

author: Sean Bechhofer (github.com/seanbechhofer)
date: 2022-03-15
labels: gates, triggers, randomness

Strange Attractor is a source of chaotic modulation using systems
of differential equations such as the Lorenz System:

https://en.wikipedia.org/wiki/Lorenz_system

Lorenz System

Outputs 1, 2 and 3 are based on the *x*, *y* and *z* values generated by the
attractor.

Outputs 4, 5 and 6 are gates based on the values of *x*, *y* and *z* and
relationships between them.

Credits:
- The Europi hardware and firmware was designed by Allen Synthesis: https://github.com/Allen-Synthesis/EuroPi

# Controls

- digital_in: Pause motion when `HIGH`
- analog_in:

- knob_1: Adjust speed
- knob_2: Adjust threshold for triggers

- button_1: Decrease output voltage range; change equation system
- button_2: Increase output voltage range; change display

- output_1: x
- output_2: y
- output_3: z
- output_4: triggers/gates
- output_5: triggers/gates
- output_6: triggers/gates

# Getting Started

Outputs 1-3 provide chaotic shifting voltages.
Outputs 4-6 provide gates/triggers.

## Basic Usage
1. Switch on
2. Connect outputs to modules
3. Enjoy randomness

## Controls
1. Knob 1 controls the speed. The sensitivity changes at noon,
allowing for very slow or very fast modulation.
2. Knob 2 adjusts the threshold used for triggers.
3. Short presses on buttons 1/2 reduce/increase the max output voltage of the CV outputs,
from 1V to 5V.
4. Long press on button 1 changes the equation system
5. Long press on button 2 changes the display between detail and graphical
6. If the digital input is `HIGH`, change is paused.

## Details

The attractors can be used to desribe a point moving in 3-D space. The
*x*, *y*, *z* coordinates are then be used to generate control
voltages and triggers.

A selection of equation systems are available, currently including
Lorzez, Rossler, Pan-X-Zhou and Rikitake -- see code for
details. Each has a set of parameters and defaults.

On startup, code runs through a number of iterations in order to
calculate the possible output ranges. This process takes
around 30 seconds per system. This is then used to normalise *x*, *y* and *z*
values to the range 0-100 for calculation of voltages on outputs 1, 2
and 3.

A system is then chosen at random.

Outputs 4, 5 and 6 are triggers, with 4 giving more frequent triggers
than 5 and 6. Output 4 takes the normalised value of output 1 and sets
it `HIGH` if the integer portion is even. Output 5 is set high when
*(y+z - 2\*x)* is above an (adjustable) threshold, similarly for
output 6 and *(z+x - 2\*y)*.

The display will show current values for outputs 1, 2, 3, speed,
threshold, voltage range, triggers 4, 5 and 6 when `HIGH` and if the
movement is frozen.

A long press on button 1 changes the equation system. Note that this
may cause a discontinuity in the x, y and z values.

A long press on button 2 toggles between a numerical and graphical
display

If the digital input is set to `HIGH`, the system will pause.

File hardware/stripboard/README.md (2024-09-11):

# Stripboard Layouts

These designs have been generously provided by [Timmoneer](https://github.com/stripboard-layouts), and the original files [can be found here](https://github.com/stripboard-layouts/lament-for-mills/tree/main/Allen%20Synthesis%20EuroPi).

This build hasn't been tested by Allen Synthesis, but has been found to work successfully, so if you are looking to make a lower budget build, or you are looking for a nicer platform to modify the project on, this may be the way to go!

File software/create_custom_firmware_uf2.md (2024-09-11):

# Creating a custom firmware.uf2 image for EuroPi

## Compiling the firmware on Windows
1. If not already installed, install [Docker](https://docs.docker.com/desktop/install/windows-install/)
1. If not already cloned, [create a local clone](https://docs.github.com/en/repositories/creating-and-managing-repositories/cloning-a-repository?tool=desktop) of the EuroPi repository
1. Run Docker
1. Click the windows file manager file path *inside* the root folder of your clone of the EuroPi repo (the folder named 'EuroPi', not any of the folders inside it)
    
1. Type 'cmd'
    
1. Press Enter
1. In the new terminal window, type 'software\uf2_build\build_uf2.bat'
1. Press Enter
1. Wait for .uf2 to compile (this may take some time, do not close the terminal window
1. The custom .uf2 build can be found at `EuroPi/software/uf2_build/europi-dev.uf2`

## Compiling the firmware on Mac/Linux
The instructions below describe the steps needed to build the uf2 locally on your machine for
development purposes. Alternatively you can run the script `software/uf2_build/build_uf2.sh` to
build the image in a docker container. You will need to have [docker](https://docs.docker.com/get-started/)
installed and running. See the script for execution details.
``` Bash
# install extra tools if not already done so
$ sudo apt update
$ sudo apt install cmake gcc-arm-none-eabi libnewlib-arm-none-eabi build-essential

# get micropython source from github repo
# choose latest stable version instead of the master branch
$ git clone -b v1.20.0 https://github.com/micropython/micropython.git

# fetch submodules
$ cd micropython
$ make -C ports/rp2 submodules

# build tools
$ make -C mpy-cross

# enter the dir for our hardware port
$ cd ports/rp2

$ ls
# files that should be frozen and included in the firmware should be placed in the 'modules' dir
# so thats 'micropython/ports/rp2/modules/'
# what should be done here is written below
# once that has been done you can continue to make the firmware

# optional clean up
$ make clean

# build the firmware
$ make
```

## Modules dir
after the files for EuroPi, EuroPi contrib and ssd1306 are inserted
the structure of the modules dir should look like this:
```
micropython/ports/rp2/modules/
├── _boot_fat.py
├── bootloader.py
├── _boot.py
├── calibrate.py
├── contrib
│   ├── bernoulli_gates.py
│   ├── coin_toss.py
│   ├── consequencer.py
│   ├── cvecorder.py
│   ├── diagnostic.py
│   ├── hamlet.py
│   └── ...
├── europi.py
├── europi_script.py
├── experimental
│   ├── __init__.py
│   └── knobs.py
├── main.py (optional)
├── rp2.py
├── setup.py
├── ssd1306.py
├── ui.py
└── version.py
```
_boot.py should be modified to look like this: (increase progsize)
``` Python
import os
import machine, rp2

bdev = rp2.Flash()
try:
    vfs = os.VfsLfs2(bdev, progsize=1024)
except:
    os.VfsLfs2.mkfs(bdev, progsize=1024)
    vfs = os.VfsLfs2(bdev, progsize=1024)
os.mount(vfs, "/")

del os, bdev, vfs
```
main.py could look like this: (It's important to call the garbage collector to make space for the software)
``` Python
import gc
gc.collect()
from contrib.menu import *
BootloaderMenu(EUROPI_SCRIPTS).main()
```

## Import priority
When using import in micropython it will look for the file according to the priority defined by the position in sys.path.
So it will look at / and /lib first, before looking in the frozen firmware modules.
However if the frozen modules of the firmware include a main.py it will autostart this and ignore any main.py located in /.

## Freezing bytecode instead of source code
By default the files from the modules dir will be frozen (included in the firmware) as python source files (.py). Alternatively it is also possible to freeze the precompiled bytecode generated from these source files. Using precompiled bytecode instead of raw source code will reduce RAM usage might slightly improve execution performance. To freeze bytecode instead of source code manifest.py can be altered to look like this:

micropython/ports/rp2/boards/manifest.py
``` Python
freeze_as_mpy("$(PORT_DIR)/modules")
freeze("$(MPY_DIR)/drivers/onewire")
freeze("$(MPY_DIR)/drivers/dht", "dht.py")
include("$(MPY_DIR)/extmod/uasyncio/manifest.py")
include("$(MPY_DIR)/drivers/neopixel/manifest.py")
```

More details about the benefits of bytecode and documentation about manifest.py can be found here: https://docs.micropython.org/en/latest/reference/manifest.html

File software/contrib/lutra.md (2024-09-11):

# Lutra

Lutra is a re-imagining of [Expert Sleepers' Otterley](https://expert-sleepers.co.uk/otterley.html) module.

Each output channel is a free running LFO with a subtly different clock speed. The spread of clock speeds is controlled
by `k2` (and optionally `ain` -- see configuration below)

## Wave Shapes

The shape of the output wave can be changed by pressing `b2` while the module is running. This choice is saved to
the module and will be re-loaded every time `Lutra` starts. Available wave shapes are:
- Sine Wave Sine
- Square Wave Square
- Triangle Wave Triangle
- Saw Wave Saw
- Ramp Wave Ramp

When pressing `b2` to select the wave shape, the selected shape will briefly appear in the upper left corner of the
screen.

## CV Input Configuration

By default CV signals applied to `ain` will adjust the spread of the output waves.  If preferred, this can be changed
to control the overall speed of the waves instead by creating/editing `/config/Lutra.json` on the module.

```json
{
    "AIN_MODE": "spread"
}
```

- `AIN_MODE`: sets the mode for `ain`. Must be one of `spread` or `speed`.  If set to `spread` the spread of clock
  speeds of the outputs is controlled by `ain`.  If set to `speed` the master clock speed is controlled by `ain`.

`ain` is expected to receive signals from zero to `MAX_INPUT_VOLTAGE` (default 12V -- see
[EuroPi configuration](/software/CONFIGURATION.md)).  Increasing the voltage will increase the speed or spread of
the LFOs.  Decreasing the speed/spread is not allowed, as EuroPi cannot accept negative voltages.  Instead it is
recommended to set `k1` and `k2` to set the minimum desired speed & spread with `ain` unpatched. Then send an
attenuated signal into `ain` to increase the speed/spread as desired.

## Knob Control

Turning `k1` fully anticlockwise will set the clock speed to the slowest setting. Turning `k1` fully clockwise will set
the clock speed to the fastest setting.

Turning `k2` fully anticlockwise will set the spread of the waves to zero; every output will have the same clock speed,
(though depending on previous settings and random noise) they may be phase-shifted from each other.

Turning `k2` clockwise will gradually increase the speed of `cv2-6`, with each output becoming slightly faster than
the previous one. i.e. `cv2` will be faster than `cv1`, `cv3` will be faster than `cv2`, etc...

At the maximum clockwise position, the speeds of `cv2-6` will be common harmonic intervals from `cv1`, as shown on the
table below:

| CV Output | Ratio w/ `cv1 | Max speed multiplier |
|---|---|---|
| `cv1` | 1:1 | x1 |
| `cv2` | 6:5 | x1.2 |
| `cv3` | 5:4 | x1.25 |
| `cv4` | 4:3 | x1.3333... |
| `cv5` | 3:2 | x1.5 |
| `cv6` | 2:1 | x2 |

## Re-syncing

When `b1` is pressed or `din` receives a high voltage all CV outputs are temporarily halted. Once `b1` is released
_and_ the signal on `din` drops back to `0.0V` the output signals will begin again, starting in their initial,
synchronized state. This allows a very short gate (trigger) signal to reset all of the waves to re-synchronize them,
or a longer gate can be used to hold the outputs at zero for as long as desired.

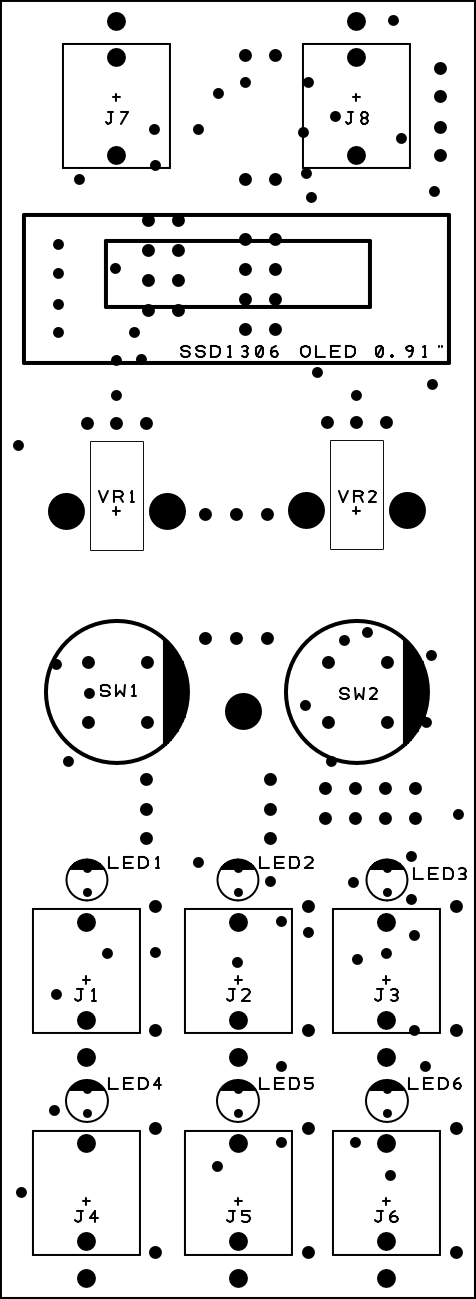
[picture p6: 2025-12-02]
hardware/schematic/europi-v1-pcb.png

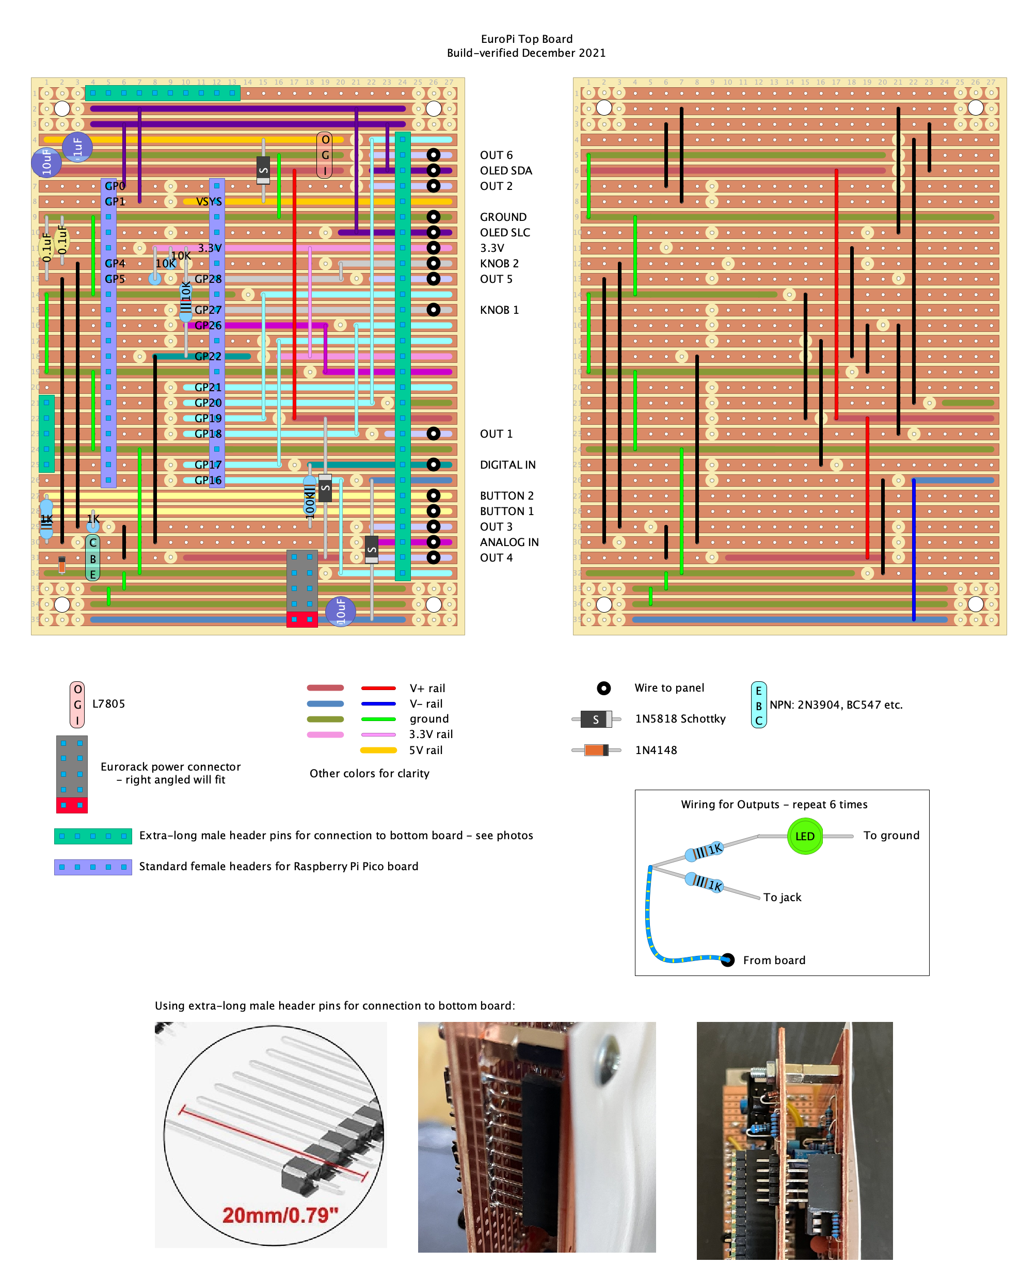
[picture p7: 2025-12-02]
hardware/stripboard/top_board.png

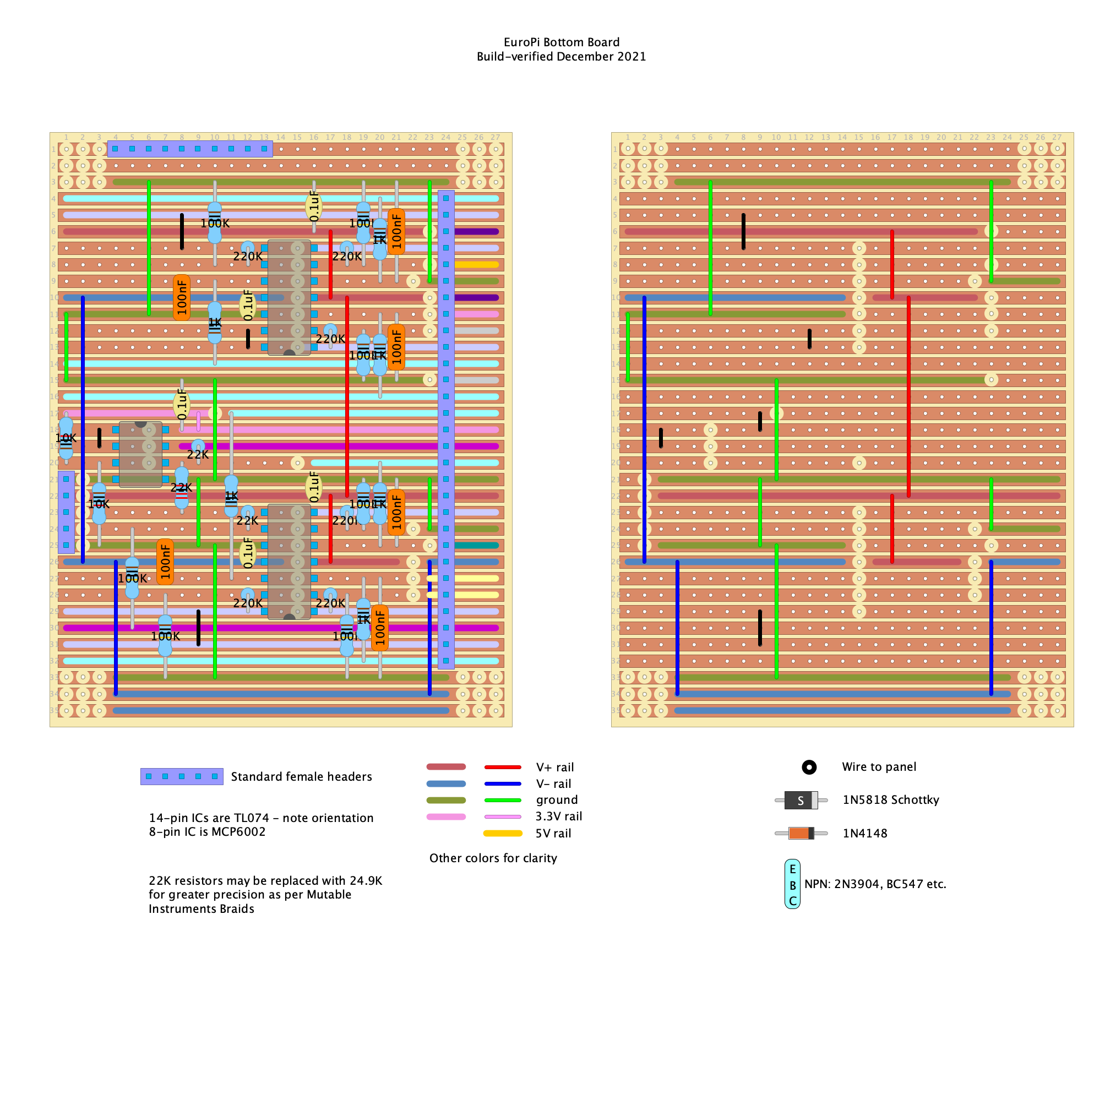
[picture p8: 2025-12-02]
hardware/stripboard/bottom_board.png

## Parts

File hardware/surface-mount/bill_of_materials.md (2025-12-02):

# Bill of Materials

In addition to the EuroPi-SMD PCB (bought from Allen Synthesis or a third-party supplier), you will need the following components to complete your build.
You will also need one 3.5mm cable (normal Eurorack patch cable) to perform the calibration process.

| Component | Quantity | Value | Description | Suggested Supplier
|-|-|-|-|-|
| LED1 - LED6 | 6 | L-424HDT | 3mm LED | [CPC](https://cpc.farnell.com/kingbright/l-424hdt/led-flat-top-3mm-red/dp/SC11541)<br>[Mouser](https://www.mouser.co.uk/ProductDetail/Kingbright/WP424IDT?qs=58z0TXQGVSSLYuj%2FWm1qPQ%3D%3D)
| VR1 - VR2 | 2 | 10k | 10 Kiloohm Linear Rotary Potentiometer | [CPC](https://cpc.farnell.com/alps/rk09k11310kb/potentiometer-10k-lin/dp/RE04560)<br>[Thonk](https://www.thonk.co.uk/shop/alpha-9mm-pots-vertical-t18/) (B10K - T18 Shaft - Alpha Vertical Potentiometer)<br>[Mouser](https://www.mouser.co.uk/ProductDetail/BI-Technologies-TT-Electronics/P0915N-QC15BR50K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)<br>**NOTE: Any resistance value between 5K and 100K will work for the potentiometers**
| SW1 - SW2 | 2 | D6RXX F1 LFS | C&K Tactile Switch (Non-Illuminated) | [Thonk](https://www.thonk.co.uk/shop/radio-music-switch/)<br>[Mouser (Black)](https://www.mouser.co.uk/ProductDetail/CK/D6R90F1LFS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)
| OLED1 | 1 | 0.91" SSD1306 | I2C OLED Display | [CPC](https://cpc.farnell.com/winstar/wea012832fwpp3n00000/oled-display-128x32-white-i2c/dp/SC15661)<br>**Note: The surface-mount build does not support 'The Pi Hut' style OLEDs, they WILL NOT WORK due to different pinouts.**
| J1 - J8 | 8 | PJ398SM | Thonkiconn 3.5mm Mono Jack | [Thonk](https://www.thonk.co.uk/shop/thonkiconn/)<br>[Mouser](https://www.mouser.co.uk/ProductDetail/Adafruit/4031?qs=u16ybLDytRatVTT4ndlXOw%3D%3D)<br>[Banananuts](https://www.thonk.co.uk/shop/bananuts/)<br>[Cosmonuts](https://www.thonk.co.uk/shop/cosmonuts/)
| CONN0 | 2 (pairs) | 20x1 2.54mm | Pico Connection Header (Male + Female) | CPC:<br>[Male](https://cpc.farnell.com/harwin/m22-2012005/header-vertical-1row-20way/dp/CN14644), [Female](https://cpc.farnell.com/multicomp/2212s-20sg-85/socket-pcb-1-row-20way/dp/CN14539)<br>Mouser:<br>[Male](https://www.mouser.co.uk/ProductDetail/Amphenol-FCI/10129378-920001BLF?qs=0lQeLiL1qyYln8p37ftVpg%3D%3D), [Female](https://www.mouser.co.uk/ProductDetail/Samtec/CES-120-02-T-S-RA?qs=0lQeLiL1qyZzf%2Fbgtv%2FkJg%3D%3D)
| | 2 | T18 Shaft | Knobs | [Thonk](https://www.thonk.co.uk/shop/1900h-t18/)<br>**NOTE: If you buy D-Shaft potentiometers, the knobs must be 'Reverse-D-Shaft' type.<br>Any knobs which fit may be chosen, but Mouser does not stock the standard suggestion sold by Thonk**
| | 1 | 10 - 16 Pin | Eurorack Power Cable | [Thonk](https://www.thonk.co.uk/shop/eurorack-power-cables/)<br>**Note: Mouser does not stock the correct cable at time of writing. Other suppliers will provide the correct part, but always double check that the polarity is correct (red stripe is always -12V)**
| | 1 | | Micro USB Cable (Capable of Data Transfer) | [CPC](https://cpc.farnell.com/pro-signal/psg91562/lead-usb-a-male-micro-b-male-black/dp/CS32732), [The Pi Hut](https://thepihut.com/products/usb-to-micro-usb-cable-0-5m)<br>[Mouser](https://www.mouser.co.uk/ProductDetail/Teltonika/PR2US08M?qs=9vOqFld9vZXl90mLcdqZXQ%3D%3D)
| | 1 | | Raspberry Pi Pico | [The Pi Hut](https://thepihut.com/products/raspberry-pi-pico)<br>[CPC](https://cpc.farnell.com/raspberry-pi/raspberry-pi-pico/raspberry-pi-pico-rp2040-mcu-board/dp/SC17106)<br>[Mouser](https://www.mouser.co.uk/ProductDetail/Raspberry-Pi/SC0915?qs=T%252BzbugeAwjgnLi4azxXVFA%3D%3D)<br>**Note: Any official version of the Raspberry Pi Pico will work (W, H, or WH). Third party RP2040 boards may work, but there is no guarantee - always double check the pinout**

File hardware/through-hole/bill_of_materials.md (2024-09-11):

# Bill of Materials

In addition to the Front Panel, Jack PCB, and Pico PCB (bought from Allen Synthesis or a third-party supplier), you will need the following components to complete your build.
You will also need one 3.5mm cable (normal Eurorack patch cable) to perform the calibration process.

Please note that a few of these are multi-packs of components, and there may well be cheaper alternatives if you are doing a single build, so as long as the specification is the same you can get any of these components from any supplier most accessible to you.

You can either add each of these components to your basket using whichever suppliers you prefer, or alternatively use the complete [Mouser Shopping Basket](https://www.mouser.co.uk/ProjectManager/ProjectDetail.aspx?AccessID=b8e6a0d666) and then buy the few components that Mouser doesn't stock (Knobs, OLED, and Eurorack Power Cable) elsewhere.
If buying in bulk there are likely other suppliers that are cheaper - this BOM is compiled for DIY builders aiming to build 1-5 EuroPis at once.

| Component | Quantity | Value | Description | Suggested Supplier
|-|-|-|-|-|
| R1 - R12, R19 - R20 | 14 | 1k | 1 Kiloohm Resistor | [CPC](https://cpc.farnell.com/unbranded/mf25-1k/resistor-0-25w-1-1k/dp/RE03722)<br>[Mouser](https://www.mouser.co.uk/ProductDetail/YAGEO/MF0207FRE52-1K?qs=8uu3sA0mUdvCQE3OPmDzOQ%3D%3D)
|R13 - R18 | 6 | 4.7k | 4.7 Kiloohm Resistor | [CPC](https://cpc.farnell.com/unbranded/mf25-4k7/resistor-0-25w-1-4k7/dp/RE03757)<br>[Mouser](https://www.mouser.co.uk/ProductDetail/TE-Connectivity-Holsworthy/LR1F4K7?qs=ip69W3eHERXYYCvJ5kqIlw%3D%3D)
| R21 - R23 | 3 | 22k | 22 Kiloohm Resistor | [CPC](https://cpc.farnell.com/unbranded/mf25-22k/resistor-0-25w-1-22k/dp/RE03743)<br>[Mouser](https://www.mouser.co.uk/ProductDetail/YAGEO/MFR25SFTE26-20K?qs=xZ%2FP%252Ba9zWqbQbDvFESXcPA%3D%3D)
| R24 - R26 | 3 | 10k | 10 Kiloohm Resistor | [CPC](https://cpc.farnell.com/unbranded/mf25-10k/resistor-0-25w-1-10k/dp/RE03723)<br>[Mouser](https://www.mouser.co.uk/ProductDetail/YAGEO/MFR50SJT-52-10K?qs=xZ%2FP%252Ba9zWqZ4kQrxBn79Xw%3D%3D)
| R27 - R34 | 8 | 100k | 100 Kiloohm Resistor | [CPC](https://cpc.farnell.com/unbranded/mf25-100k/resistor-0-25w-1-100k/dp/RE03724)<br>[Mouser](https://www.mouser.co.uk/ProductDetail/YAGEO/MFR-25FRF52-100K?qs=5furm%2FeQHzRFPw%252B0Jam4HA%3D%3D)
| R35 - R40 | 6 | 220k | 220 Kiloohm Resistor | [CPC](https://cpc.farnell.com/unbranded/mf25-220k/resistor-0-25w-1-220k/dp/RE03744)<br>[Mouser](https://www.mouser.co.uk/ProductDetail/YAGEO/MFR-25FRF52-220K?qs=oAGoVhmvjhyfB1wbipURwA%3D%3D)
| C1 - C2 | 2 | 1uF | 1 Microfarad Capacitor (Polarised)| [CPC](https://cpc.farnell.com/multicomp/mcmhr50v105m4x7/capacitor-1uf-50v-radial-105-deg/dp/CA08237)<br>[Mouser](https://www.mouser.co.uk/ProductDetail/Wurth-Elektronik/860020672005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)
| C3 - C14 | 12 | 100nF | 100 Nanofarad Capacitor (Non-Polarised)| [CPC](https://cpc.farnell.com/multicomp/mcrr50104x7rk0050/capacitor-100nf-50v/dp/CA06296)<br>[Mouser](https://www.mouser.co.uk/ProductDetail/Vishay-BC-Components/K104K10X7RF53H5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)
| C15 - C16 | 2 | 10uF | 10 Microfarad Capacitor (Polarised)| [CPC](https://cpc.farnell.com/panasonic/eeueb1j100s/capacitor-10uf-63v-5x11mm/dp/CA08350)<br>[Mouser](https://www.mouser.co.uk/ProductDetail/Wurth-Elektronik/860010572002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)
| D1 - D4 | 4 | 1N5817 | Schottky Diode | [CPC](https://cpc.farnell.com/multicomp-pro/1n5817/schottky-rectifier-1a-20v-do-204al/dp/SC15528)<br>[Mouser](https://www.mouser.co.uk/ProductDetail/Diotec-Semiconductor/1N5817?qs=OlC7AqGiEDkUjhPY%2FT8RQg%3D%3D)
| LED1 - LED6 | 6 | L-424HDT | 3mm LED | [CPC](https://cpc.farnell.com/kingbright/l-424hdt/led-flat-top-3mm-red/dp/SC11541)<br>[Mouser](https://www.mouser.co.uk/ProductDetail/Kingbright/WP424IDT?qs=58z0TXQGVSSLYuj%2FWm1qPQ%3D%3D)
| VR1 - VR2 | 2 | 10k | 10 Kiloohm Linear Rotary Potentiometer | [CPC](https://cpc.farnell.com/alps/rk09k11310kb/potentiometer-10k-lin/dp/RE04560)<br>[Thonk](https://www.thonk.co.uk/shop/alpha-9mm-pots-vertical-t18/) (B10K - T18 Shaft - Alpha Vertical Potentiometer)<br>[Mouser](https://www.mouser.co.uk/ProductDetail/BI-Technologies-TT-Electronics/P0915N-QC15BR50K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)<br>**NOTE: Any resistance value between 5K and 100K will work for the potentiometers**
| SW1 - SW2 | 2 | D6RXX F1 LFS | C&K Tactile Switch (Non-Illuminated) | [Thonk](https://www.thonk.co.uk/shop/radio-music-switch/)<br>[Mouser (Black)](https://www.mouser.co.uk/ProductDetail/CK/D6R90F1LFS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)
| OLED1 | 1 | 0.91" SSD1306 | I2C OLED Display | [CPC](https://cpc.farnell.com/winstar/wea012832fwpp3n00000/oled-display-128x32-white-i2c/dp/SC15661)<br>[The Pi Hut](https://thepihut.com/products/0-91-oled-display-module)<br>**Note: Mouser does not stock the OLED required, and alternative suppliers to those listed may be too wide to fit in the module - always double check the datasheet and see the note below**
| J1 - J8 | 8 | PJ398SM | Thonkiconn 3.5mm Mono Jack | [Thonk](https://www.thonk.co.uk/shop/thonkiconn/)<br>[Mouser](https://www.mouser.co.uk/ProductDetail/Adafruit/4031?qs=u16ybLDytRatVTT4ndlXOw%3D%3D)<br>[Banananuts](https://www.thonk.co.uk/shop/bananuts/)<br>[Cosmonuts](https://www.thonk.co.uk/shop/cosmonuts/)
| CONN0 | 2 (pairs) | 20x1 2.54mm | Pico Connection Header (Male + Female) | CPC:<br>[Male](https://cpc.farnell.com/harwin/m22-2012005/header-vertical-1row-20way/dp/CN14644), [Female](https://cpc.farnell.com/multicomp/2212s-20sg-85/socket-pcb-1-row-20way/dp/CN14539)<br>Mouser:<br>[Male](https://www.mouser.co.uk/ProductDetail/Amphenol-FCI/10129378-920001BLF?qs=0lQeLiL1qyYln8p37ftVpg%3D%3D), [Female](https://www.mouser.co.uk/ProductDetail/Samtec/CES-120-02-T-S-RA?qs=0lQeLiL1qyZzf%2Fbgtv%2FkJg%3D%3D)
| CONN1 - CONN4 | 2 (pairs) | 4x2 2.54mm | PCB Connection Header (Male + Female) | CPC:<br>[Male](https://cpc.farnell.com/harwin/m20-9980445/header-2row-4way/dp/CN14381), [Female](https://cpc.farnell.com/multicomp/2214s-08sg-85/socket-pcb-2-54mm-2-row-vert-8way/dp/CN18449)<br>Mouser:<br>[Male](https://www.mouser.co.uk/ProductDetail/Amphenol-FCI/10129381-908002BLF?qs=DXv0QSHKF4wp0EFafi7%252BkA%3D%3D), [Female](https://www.mouser.co.uk/ProductDetail/TE-Connectivity/5-534206-4?qs=Eln3I3szM1ldJZZch%252BwNBQ%3D%3D)
| CONN5 | 1 | 4x1 2.54mm | I2C Header (Male) | [CPC](https://cpc.farnell.com/multicomp/2211s-04g/header-1-row-vert-4way/dp/CN14489)<br>[Mouser](https://www.mouser.co.uk/ProductDetail/Samtec/TMS-104-02-T-S?qs=0lQeLiL1qyYGrmA47bgfvw%3D%3D)
| CONN6 | 1 | 5x2 2.54mm | Eurorack Power Header (Shrouded) | [CPC](https://cpc.farnell.com/3m/n2510-6002rb/2-54mm-header-straight-10-way/dp/CN20355)<br>[Mouser](https://www.mouser.co.uk/ProductDetail/Amphenol-FCI/75869-101LF?qs=IfYaNh1cBzKYl6r7KisYeA%3D%3D)
| TL074-1 - TL074-2 | 2 | TL074 DIP | Quad Operational Amplifier (+ Socket) | CPC:<Br>[Op-Amp](https://cpc.farnell.com/texas-instruments/tl074acn/ic-op-amp-quad-jfet-dip14/dp/SC16602), [Socket](https://cpc.farnell.com/unbranded/mc-2227-14-03-f1/socket-ic-dil-0-3-tube-34-14way/dp/SC08125)<br>Mouser:<br>[Op-Amp](https://www.mouser.co.uk/ProductDetail/Texas-Instruments/TL074CNE4?qs=odmYgEirbwzZM%2F3R%2FF4zPw%3D%3D), [Socket](https://www.mouser.co.uk/ProductDetail/TE-Connectivity/1-2199298-3?qs=fK8dlpkaUMtBOtVI99wRlQ%3D%3D)
| MCP6002 | 1 | MCP6002 DIP | Dual Operational Amplifier (+ Socket) | CPC:<br>[Op-Amp](https://cpc.farnell.com/microchip/mcp6002-i-p/ic-op-amp-1-8v-1mhz-dual-pdip8/dp/SC17118), [Socket](https://cpc.farnell.com/multicomp/spc15494/dip-socket-8pos-2row-2-54mm-th/dp/SC15358)<br>Mouser:<br>[Op-Amp](https://www.mouser.co.uk/ProductDetail/Microchip-Technology/MCP6002-I-P?qs=Ux5rHyN1IXStLRM979v6Rg%3D%3D), [Socket](https://www.mouser.co.uk/ProductDetail/Mill-Max/110-41-308-41-001000?qs=dvxwXVM4mZVj1CY1TePuww%3D%3D)
| Q1 | 1 | 2N3904 | NPN Transistor | [CPC](https://cpc.farnell.com/multicomp-pro/2n3904/transistor-npn-to-92/dp/SC15978)<br>[Mouser](https://www.mouser.co.uk/ProductDetail/Diotec-Semiconductor/2N3904?qs=OlC7AqGiEDlYMySw5i2rlg%3D%3D)
| 7805 | 1 | L7805ABV | 5V Linear Voltage Regulator | [CPC](https://cpc.farnell.com/stmicroelectronics/l7805abv/ic-v-reg-5v/dp/SC10586)<br>[Mouser](https://www.mouser.co.uk/ProductDetail/Texas-Instruments/LM7805CT-NOPB?qs=OYMYEaN9QmBS2GvaX6GSkQ%3D%3D)
| | 1 | 11mm | M2.5 PCB Standoff + 2 Screws | CPC:<br>[Standoff](https://cpc.farnell.com/ettinger/05-02-113/spacer-hex-m2-5-11mm-length-brass/dp/PC01763), [Screws](https://cpc.farnell.com/unbranded/pp2m5-6/screw-pan-pozi-m2-5-x-6mm-100pk/dp/FN02140)<br>Mouser:<br>[Standoff](https://www.mouser.co.uk/ProductDetail/Wurth-Elektronik/970110151?qs=byeeYqUIh0MbOZEhnA3K1A%3D%3D), [Screws](https://www.mouser.co.uk/ProductDetail/Keystone-Electronics/29300?qs=H3YudI7YoxU32i5yvk535w%3D%3D)
| | 2 | T18 Shaft | Knobs | [Thonk](https://www.thonk.co.uk/shop/1900h-t18/)<br>**NOTE: If you buy D-Shaft potentiometers, the knobs must be 'Reverse-D-Shaft' type.<br>Any knobs which fit may be chosen, but Mouser does not stock the standard suggestion sold by Thonk**
| | 1 | 10 - 16 Pin | Eurorack Power Cable | [Thonk](https://www.thonk.co.uk/shop/eurorack-power-cables/)<br>**Note: Mouser does not stock the correct cable at time of writing. Other suppliers will provide the correct part, but always double check that the polarity is correct (red stripe is always -12V)**
| | 1 | | Micro USB Cable (Capable of Data Transfer) | [CPC](https://cpc.farnell.com/pro-signal/psg91562/lead-usb-a-male-micro-b-male-black/dp/CS32732), [The Pi Hut](https://thepihut.com/products/usb-to-micro-usb-cable-0-5m)<br>[Mouser](https://www.mouser.co.uk/ProductDetail/Teltonika/PR2US08M?qs=9vOqFld9vZXl90mLcdqZXQ%3D%3D)
| | 1 | | Raspberry Pi Pico | [The Pi Hut](https://thepihut.com/products/raspberry-pi-pico)<br>[CPC](https://cpc.farnell.com/raspberry-pi/raspberry-pi-pico/raspberry-pi-pico-rp2040-mcu-board/dp/SC17106)<br>[Mouser](https://www.mouser.co.uk/ProductDetail/Raspberry-Pi/SC0915?qs=T%252BzbugeAwjgnLi4azxXVFA%3D%3D)<br>**Note: Any official version of the Raspberry Pi Pico will work (W, H, or WH). Third party RP2040 boards may work, but there is no guarantee - always double check the pinout**

#### Note about OLED
The OLED has two suppliers listed, each with different pin configurations. The module supports either of these two configurations (the most common), but no others, so make sure that the one you buy, wherever you source it, has one of these two configurations.
It also *must* be 36mm or less. There are some displays which are 38mm wide, which will not only not fit within the width of the module, but will also leave the display off-centre in relation to the panel cutout. You can check the datasheet of any display before you buy to determine the width, but both of the displays listed in the BOM above are the correct 36mm.

OLED Pin Configurations
OLED Width

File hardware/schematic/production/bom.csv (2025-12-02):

Designator | Footprint | Quantity | Value | LCSC Part #
C1, C2 | 0805 | 2 | 10uF
C10, C11, C12, C13, C14, C16, C17, C18, C4, C5, C6, C7, C9 | 0603 | 13 | 100nF
C15 | 0603 | 1 | 1nF
C3 | 0603 | 1 | 1uF
D1, D2, D5 | D_SMA | 3 | D | C5356810
D3 | D_SMA | 1 | D
J1 | power-header-10-pin-unlabelled | 1 | Conn_02x05_Odd_Even
J10 | jack-thonkiconn-mono | 1 | Output 6 Jack
J11, J2 | PinHeader_1x04_P2.54mm_Vertical | 2 | Conn_01x04_Pin
J3 | jack-thonkiconn-mono | 1 | Output 1 Jack
J4 | jack-thonkiconn-mono | 1 | Output 4 Jack
J5 | jack-thonkiconn-mono | 1 | Analogue Input Jack
J6 | jack-thonkiconn-mono | 1 | Output 2 Jack
J7 | jack-thonkiconn-mono | 1 | Output 5 Jack
J8 | jack-thonkiconn-mono | 1 | Digital Input Jack
J9 | jack-thonkiconn-mono | 1 | Output 3 Jack
LED1, LED2, LED3, LED4, LED5, LED6 | led-3mm | 6 | LED
Q1 | SOT-89-3 | 1 | 2N2222 | C21714170
R1, R13, R14, R16, R17, R2, R26, R27, R29, R3, R30, R38, R39, R4 | 0603 | 14 | 1K
R10, R21, R22, R33, R34, R9 | 0603 | 6 | 220K
R11, R12, R24, R25, R36, R37 | 0603 | 6 | 4K7
R15, R19, R20, R31, R32, R35, R7, R8 | 0603 | 8 | 100K
R18, R23, R28 | 0603 | 3 | 22K
R40, R5, R6 | 0603 | 3 | 10K
SW1, SW2 | switch-momentary-c&k | 2 | SW_Push
U2 | raspberry-pi-pico | 1 | PICO_RP2040
U3, U4 | SOIC-14_3.9x8.7mm_P1.27mm | 2 | TL074 | C6963
U5 | SOIC-8_3.9x4.9mm_P1.27mm | 1 | MCP6002-xSN | C7377
U6 | TO-252-2 | 1 | L7805 | C7394043
VR1 | potentiometer-9mm | 1 | KNOB 1
VR2 | potentiometer-9mm | 1 | KNOB 2

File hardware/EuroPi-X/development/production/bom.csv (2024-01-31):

Designator | Footprint | Quantity | Value | LCSC Part #
C1_3 | 0402 | 1 | 1u | C52923
C1_2, C2_3, C3_3, C6_2, C7 | 0402 | 5 | 100n | C1525
C1, C2, C4, C5 | 0805 | 4 | 2.2uF | C377773
C2_2, C3_2, C4_2, C5_2 | 0402 | 4 | 100p | C1546
C3, C6 | 0805 | 2 | 10uF | C377773
DAC1 | MSOP-10_3x3mm_P0.5mm | 1 | MCP4728 | C478093
DS1 | KH-FPC0.5-H2.0SMT-30P-QCH FPC Connector 30 pin | 1 | OLED-128O064D | C3250002
J1_2, J2_2, J8, J9 | PinHeader_1x06_P2.54mm_Vertical | 4 | Conn_01x06_Pin
J1 | PinHeader_1x08_P2.54mm_Vertical_SMD_Pin1Left | 1 | Conn_01x08_Male | C5160791
J2, J3 | PinHeader_1x02_P2.54mm_Vertical_SMD_Pin1Right | 2 | Conn_01x02_Pin | C5160785
JP1, JP2 | SolderJumper-2_P1.3mm_Bridged_RoundedPad1.0x1.5mm | 2 | Close for I2C
R1_3 | 0402 | 1 | 2K2 | C25879
R1_2, R10_2, R10, R11_2, R13, R14, R2_3, R2_2, R3_3, R4_3, R5_2, R5, R6, R8_2, R9_2, R9 | 0402 | 16 | 100K | C25741
R1, R2, R3 | 0603 | 3 | 10K | C25804
R11, R15, R3_2, R7 | 0402 | 4 | 270K | C170277
R12_2, R13_2, R6_2, R7_2 | 0402 | 4 | 15K | C25756
R12, R16, R18, R19, R20, R21, R4_2, R8 | 0402 | 8 | 1K | C11702
R4 | 0603 | 1 | 330K | C23137
U1_2 | SOT-23 | 1 | LM4040DBZ-10 | C129969
U1 | SOIC-14_3.9x8.7mm_P1.27mm | 1 | TL074 | C6963
U2 | TSSOP-14_4.4x5mm_P0.65mm | 1 | MCP6004 | C50282
U3 | SOIC-14_3.9x8.7mm_P1.27mm | 1 | MCP3428 | C560166

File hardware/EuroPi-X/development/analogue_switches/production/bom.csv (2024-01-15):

Designator | Footprint | Quantity | Value | LCSC Part #
C1, C2 | 0402 | 2 | 1u | C52923
J1 | PinHeader_1x06_P2.54mm_Vertical | 1 | Conn_01x06_Pin
R1, R2 | 0402 | 2 | 2K2 | C25879
SW1, SW2 | SOT-363_SC-70-6 | 2 | ~ | C213161
TP1, TP2 | TestPoint_Pad_2.0x2.0mm | 2 | TestPoint
U1 | SOT-23 | 1 | LM4040DBZ-4.1 | C202194
U2 | SOT-23 | 1 | LM4040DBZ-2.0 | C144273

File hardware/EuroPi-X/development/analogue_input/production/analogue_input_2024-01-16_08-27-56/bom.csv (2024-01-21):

Designator | Footprint | Quantity | Value | LCSC Part #
C1 | 0402 | 1 | 1u | C52923
C2, C3 | 0402 | 2 | 100n | C1525
J1, J2, J3, J4 | jack-thonkiconn-mono | 4 | Thonkiconn_Mono_Jack
J6 | PinHeader_1x06_P2.54mm_Vertical | 1 | Conn_01x06_Pin
R1 | 0402 | 1 | 2K2 | C25879
R10, R11, R14, R15, R16, R17, R2, R3, R4, R5, R8, R9 | 0402 | 12 | 100K | C25741
R12, R13, R6, R7 | 0402 | 4 | 15K | C25756
U1 | SOT-23 | 1 | LM4040DBZ-10 | C129969
U2 | TSSOP-14_4.4x5mm_P0.65mm | 1 | MCP6004 | C50282
U3 | SOIC-14_3.9x8.7mm_P1.27mm | 1 | MCP3428 | C560166

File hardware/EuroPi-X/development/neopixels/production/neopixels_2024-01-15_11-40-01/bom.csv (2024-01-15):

Designator | Footprint | Quantity | Value | LCSC Part #
D1, D10, D11, D12, D2, D3, D4, D5, D6, D7, D8, D9 | LED_SK6805_PLCC4_2.4x2.7mm_P1.3mm | 12 | SK6805 | C2890036
J1 | PinHeader_1x04_P2.54mm_Vertical | 1 | Conn_01x04_Pin
Q1 | SOT-23 | 1 | BSS138
R1, R2 | 0402 | 2 | 10K | C25744

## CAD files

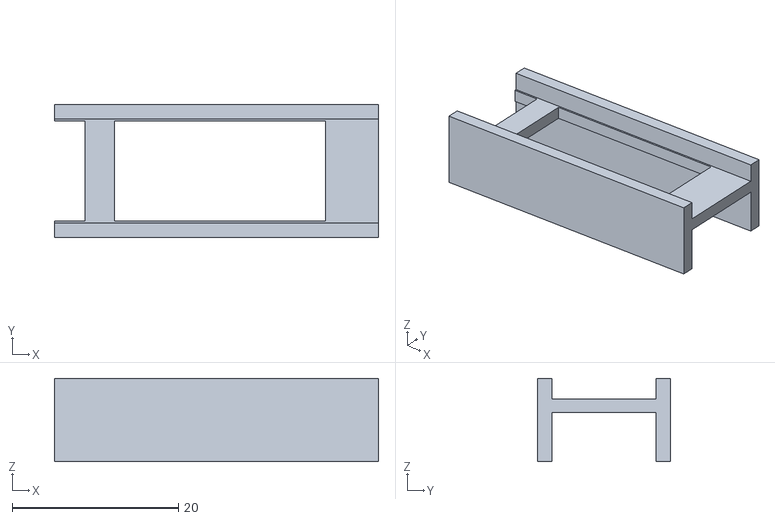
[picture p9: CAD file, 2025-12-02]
hardware/OLED_Stand/OLED_Stand.stl
39.0 x 16.0 x 10.0

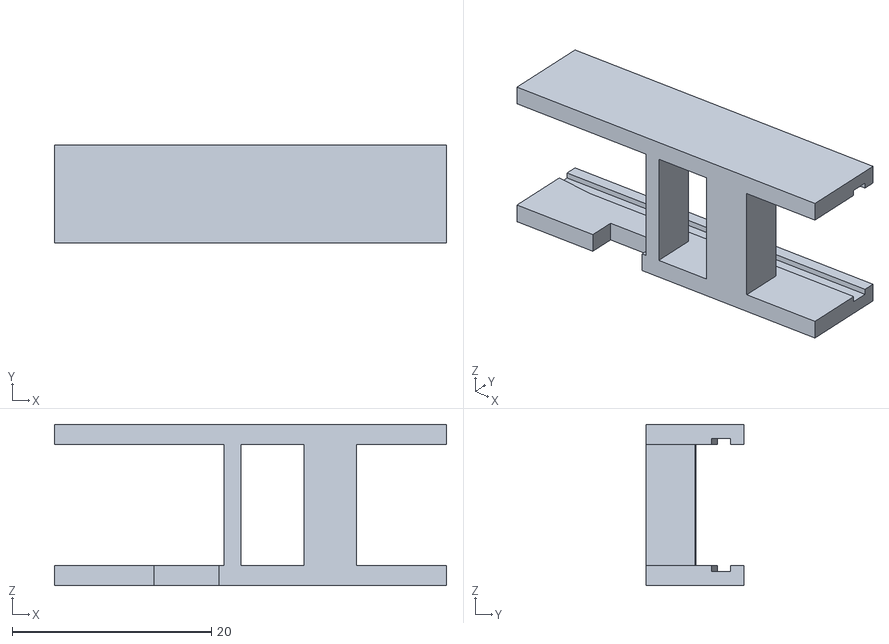
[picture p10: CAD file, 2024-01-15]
hardware/OLED_Stand/OLED_Stand_Pi_Hut.stl
39.3 x 9.80 x 16.1

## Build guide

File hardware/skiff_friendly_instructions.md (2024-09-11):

# Skiff-Friendly Build Instructions

If you have opened this file without being directed here from the normal build guide, you are probably in the wrong place. Follow the normal build guide from the beginning and only access these instructions by clicking the links that say [Skiff Friendly Option]().

### Step 1

1. Instead of soldering female headers as per the normal build, push the Pico onto the board using its male headers only
2. Solder the Pico from the back
3. [Now go back to the normal build](https://github.com/Allen-Synthesis/EuroPi/blob/main/hardware/EuroPi/build_guide.md#large-capacitors)

### Step 2

1. Bend the 7805's legs 90 degrees using a pair of pliers. Look at the photos below to see where to bend them and in which direction
2. Push the 7805 into the PCB footprint and solder
3. You may need to put a piece of tape between the 7805 and the Pico to prevent the metal back of the 7805 from touching the pins or USB port of the Pico
4. [Now go back to the normal build](https://github.com/Allen-Synthesis/EuroPi/blob/main/hardware/EuroPi/build_guide.md#jack-pcb)

_DSC2402
_DSC2403

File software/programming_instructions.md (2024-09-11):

# Setting up and programming the EuroPi

This document will take you through the steps to get your module ready to program.

> **Note**
> If you already have any version of the firmware or any other code loaded onto your EuroPi and want to ensure a clean installation, or you just want to make sure you have all the most recent scripts available, first follow these instructions:

1. Download [flash_nuke.uf2](https://learn.adafruit.com/getting-started-with-raspberry-pi-pico-circuitpython/circuitpython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) from Adafruit.

2. Holding down the white button labeled 'BOOTSEL' on the Raspberry Pi Pico, connect the module to your computer via the USB cable.
> **Note**
> If you are already running the menu system on the EuroPi (with a version greater or equal to X.X.X) and would rather not take the module out of your rack, you can instead run the script `_Bootloader Mode` while the module is connected to your computer over USB, and the module will enter bootloader mode

_DSC2400

3. Open your file manager and drag and drop the downloaded `flash_nuke.uf2` onto the new drive named 'RPI-RP2'. This will wipe your Pico clean, ready for a new installation of the firmware.

4. The Pico will automatically eject once the process is completed.

5. Continue to [Setting Up](#setting-up) as normal.

 ## Optional Quick start

> **Warning**
> This version of firmware will not let you override `main.py` nor can you modify existing scripts. Do not use this version of the firmware if you plan to write custom scripts for the EuroPi.

The quickest way to get your EuroPi flashed with the latest firmware is to head over to the [releases](https://github.com/Allen-Synthesis/EuroPi/releases) page and download the latest `europi-vX.Y.Z.uf2` file. Then follow the 'BOOTSEL' instructions above to flash the EuroPi firmware to your pico.

## Setting Up

### Downloading Thonny
To start with, you'll need to download the [Thonny IDE](https://thonny.org/). This is what you will use to program and debug the module.

Thonny

### Installing the firmware
1. Download the [most recent firmware](https://micropython.org/download/rp2-pico/) from the MicroPython website. The latest supported version is `1.22.2`.
2. Holding down the white button labeled 'BOOTSEL' on the Raspberry Pi Pico, connect the module to your computer via the USB cable.

    _DSC2400

3. Open your file manager and drag and drop the downloaded .uf2 onto the new drive named 'RPI-RP2'.
4. The Pico will automatically eject once the process is completed.

### Installing the OLED library
1. Disconnect the Pico from the USB cable.
2. Reconnect, this time without holding down the button on the back.

    _DSC2401

3. Open up Thonny if not already open, and go to the bottom right where you can select the interpreter.
4. Click to select interpreter and choose 'MicroPython (Raspberry Pi Pico)'.

    Interpreter Select

5. **Important**: Wait until the Shell window at the bottom shows the MicroPython version and the purple ```>>>``` symbol.

    

6. Click Tools -> Manage Packages to open the package manager.
7. Type 'micropython-ssd1306' into the search box and click 'Search on PyPi'
8. Click the result named 'micropython-ssd1306'.

    ssd1306 library

9. Click 'Install'.
10. You will see that a folder has been created inside the Pico named 'lib', which contains the new file 'ssd1306.py'.

    ssd1306 inside lib

### Installing the EuroPi library

Use the exact same process as for the ssd1306 library to install the europi library:
1. Type 'micropython-europi' into the search box and click 'Search on PyPi'
2. Click the result named 'micropython-europi'.

    

3. Click 'Install'.
4. You will now see several new files, including 'europi.py' alongside the 'ssd1306.py' inside the 'lib' folder.

### (Optional) Installing the EuroPi Contrib library

The EuroPi Contrib library will make user-contributed software available on your EuroPi when using the [Menu](/software/contrib/menu.md) software. To install it, follow the same steps as the previous libraries on Thonny:

1. Type 'micropython-europi-contrib' into the search box and click 'Search on PyPi'
1. Click the result named 'micropython-europi-contrib'.

    Screenshot from 2023-07-14 03-02-02

1. Click 'Install'.
1. You will now see a 'contrib' folder inside the 'lib' folder which contains several software options with the extension `.py`.

## Next Steps

Now that you have installed the europi.py and ssd1306 libraries, you are ready to take the next step with the module.

* [Option 1](#write-your-own-program-from-scratch): Start writing your own program from scratch
* [Option 2](#copy-someone-elses-program-to-run-on-your-module): Use someone else's program from the [contrib folder](/software/contrib/)
* [Option 3](#install-the-contrib-scripts-and-setup-the-menu): Install all of the contrib scripts and use the bootloader menu
* [Option 4](#calibrate-the-module): Calibrate the module for higher accuracy

### Write your own program from scratch

To program the module, just create a new Python file, and then press Ctrl-Shift-S to save as to the Raspberry Pi Pico, and name it 'main.py'.
Do not save files to the 'lib' folder, as this is just for libraries to be imported rather than programs that you will write.
Now import the entire europi library by simply adding the line 'from europi import *'

  From europi import

Now you have access to the inputs and outputs using easy methods, which you can read about more in the [README.md](/software/README.md) of the software folder.

### Copy someone else's program to run on your module

1. Use the exact same process as for the ssd1306 and europi libraries to install the europi-contrib library:
   1. In Thonny, click Tools -> Manage Packages to open the package manager.
   2. Type 'europi' into the search box and click 'Search on PyPi'
   3. Click the result named 'micropython-europi-contrib'.
   4. Click 'Install'.
2. You will now see the new directory 'contrib' inside the 'lib' folder, containing the contrib scripts.
3. You can now choose any script from inside this contrib folder to run on your module. When you've chosen, double click the file on the Pico to open it.
4. Press 'Ctrl-Shift-S' to Save As, and choose 'Raspberry Pi Pico'

  
5. Name the file ``main.py``, being careful to include the '.py' so the module knows it is a Python file. If you do not name it ``main.py``, the module will not know to automatically run your program whenever it is connected to power. Save the file to the root directory of the Pico (not inside any folders)

  
6. Now you can disconnect the module from your computer, connect it to rack power, and the your chosen script will run automatically.

### Install the contrib scripts and setup the menu

1. Make sure you've [Installed the EuroPi Contrib library](#optional-installing-the-europi-contrib-library).
2. Complete all of the steps for [Option 2](#copy-someone-elses-program-to-run-on-your-module), but you must use ``menu.py`` as the file to save to the root directory. Name it ``main.py`` as you would any other script.
3. Now you can disconnect the module from your computer, connect it to rack power, and the menu will open automatically.

One of the scripts that is installed with the menu system is named '~ Calibrate', and it requires you to send precise voltages to the module to calibrate it for the future, allowing you to input and output precise values from your module.
This is entirely optional and it will work with a usable degree of accuracy without calibration, however if you do want to then move to the ['Calibrate the module'](#calibrate-the-module) step.

#### Navigating the menu

To navigate the menu use the right knob. Turning clockwise will scroll down and turning anticlockwise will scroll up.

To run the selected program, press the either button once.  The last-run program will automatically start the next time you power-on your EuroPi.

To return to the main menu at any time, press and hold both buttons for 0.5s.

### Calibrate the module

To use the module for accurately reading and outputting voltages, you need to complete a calibration process. This will allow your specific module to account for any differences in components, such as resistor tolerances.
If you do not wish to calibrate the module and don't mind your voltages being slightly inaccurate, simply skip to the programming step and your module will use default values.

> **Note**
> If you have just installed the menu, simply run the calibration script and skip to step 2.

1. To begin, you need to choose the `calibrate.py` file and save it as `main.py` in the root directory, as we did in [Option 2](#copy-someone-elses-program-to-run-on-your-module) above. You can obtain the `calibrate.py` file from either the `lib` directory on your Pico, or from [the firmware directory in the repository](/software/firmware/calibrate.py).
2. Make sure your module is connected to rack power for the calibration process. It doesn't matter if it connected to USB as well, however if it is it will give an extra warning to turn on rack power which you need to skip using button 1.
3. Turn on the rack power supply, and the screen will display 'Calibration Mode'. If it doesn't, try [troubleshooting](../troubleshooting.md).
4. There are 2 options for calibration:
  - Low Accuracy: Only a single 10V supply is required
  - High Accuracy: A variable supply is required to produce voltages from 0-10V
  Press button 1 to choose Low Accuracy mode, or button 2 to choose High Accuracy mode.
5. Connect your voltage source to the analogue input, and input each voltage displayed on the screen. To take a reading (once your voltage is connected), press button 1.
6. Once all the required voltages have been input, you now need to disconnect the analogue input from your voltage source, and instead connect it to CV output 1.
7. Once you have connected the analogue input to CV output 1, press button 1
8. Wait for each voltage up to 10V to complete. The module will tell you once it has completed.
9. NOTE: Skip this final step if you are running the calibration script from the menu system.
The calibration process is now complete! You now need to rename or delete the 'calibrate.py' program, however DO NOT delete the new file created called 'calibration_values.py'. This file is where the calibration values are stored, and if you delete it you will have to complete the calibration again.

# Programming Limitations

As with all hardware, the EuroPi has certain limitations. Some are more obvious and are required knowledge for any user, and some are more in depth and are only relevant if you will be programming the module yourself.

### Obvious Limitations
- Analogue input is only 0-10V
- Digital input can only detect signals above 0.7V (meaning it may trigger accidentally if you have a noisy 'low' state)
- Outputs, analogue input, and knobs, have a maximum resolution of 12 bits (4096 steps)
- Debouncing of the buttons means that very fast double presses may not be detected

### In Depth Limitations
- Clock pulses shorter than approximately 0.01s (10ms) will not be reliably detected (this depends on clock speed too)
- Reading any analogue source, either the analogue input or knobs, will result in a slight delay of the script (this can be reduced by using fewer samples, at the cost of accuracy)

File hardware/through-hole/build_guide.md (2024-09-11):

# Build Guide

#### Introduction
This document will go through the assembly of the EuroPi module.
If you have bought only a Panel + PCB kit, you will need to also buy all of the components found in the [bill of materials](/hardware/EuroPi/bill_of_materials.md).

This build is entirely through-hole (not even any pre-soldered SMD components!) so don't worry if you're fairly new to DIY, these instructions should be all you need to make your module.

This guide should explain every step in enough detail, but there are some things left out for simplicity's sake, such as the fact that after each step any long legs will need to be snipped using your wire snips or scissors. This is only necessary for components with long legs, so resistors, capacitors, and LEDs. You don't need to snip anything off any of the headers, the 7805, the jacks, potentiometers, or IC sockets.

#### Skiff Friendly Build
There are two options for some of the build, one of which makes the module more skiff friendly (37mm deep as opposed to 45mm). If you wish to make the thinner version, simply click the links that say [Skiff Friendly Option](), and follow the instructions to guide you back into the normal build at the right points. Simply ignore these links if you don't mind the module being slightly deeper.

1 all

## Required tools
- Soldering Iron + Solder
- Wire Snips / Scissors
- Multimeter (Very nice to have but non-essential)

2 tools

## Preparation

#### If not already soldered, solder the headers to the Pico so that they are on the opposite side to the black integrated chips. It may help to push it into a breadboard to make sure the headers are straight
_DSC2386

## Pico PCB

The 'Pico PCB' is the PCB with the outline of the Pico on it.
The 'front' of the Pico PCB is the side with the actual Raspberry Pi Pico on it, and the 'back' is the side with the transistor outline on it.

|Front|Back|
|-----|----|
|||

#### Required Components for Pico PCB
|Component|Quantity|
|---|---|
|1k Resistor|6|
|22k Resistor|3|
|100k Resistor|8|
|220k Resistor|6|
|10k Resistor|3|
|Schottky Diode|4|
|100nF Capacitor|10|
|14 Pin IC Socket|2|
|8 Pin IC Socket|1|
|NPN Transistor|1|
|1uF Capacitor|2|
|4x2 Female Header|2|
|Shrouded Power Header|1|
|4x1 Male Header|1|
|20x1 Female Pico Header|2|
|10uF Capacitor|2|

---

### Resistors

#### Solder the 1k resistors to the front (R1, R2, R3, R4, R5, R6)
_DSC2333
_DSC2335

#### Solder the 22k resistors to the front (R21, R22, R23)
_DSC2338

#### Solder the 100k resistors to the front (R28, R29, R30, R31, R32, R33, R34)
_DSC2339

#### Solder the 220k resistors to the front (R35, R36, R37, R38, R39, R40)
_DSC2340

#### Solder the 10k resistors to the back (R24, R25, R26)
_DSC2341

#### Solder the 100k resistor to the back (R27)
_DSC2342

---

### Diodes

#### Solder the Schottky diodes to the front (D2, D3, D4), taking care of the polarity
_DSC2343

#### Solder the Schottky diode to the back (D1), taking care of the polarity
_DSC2344

---

### Small Capacitors

#### Solder the 100nF capacitors to the front (C3, C4, C5, C6, C9, C10, C11, C12, C13, C14)
_DSC2345

---

### IC Sockets

#### Solder the 14 Pin IC sockets to the front (TL072-1, TL072-2), lining up the notch with the white square on the PCB
_DSC2346

#### Solder the 8 pin IC socket to the front (MCP6002), lining up the notch with the white square on the PCB
_DSC2347

---

### Transistor

#### Solder the NPN transistor to the back (Q1), lining up the flat edge with the line on the PCB
_DSC2348

---

### Medium Capacitors

#### Solder the 1uF capacitors to the front (C1, C2), taking care of the polarity. The white stripe on the capacitor lines up with the stripe on the PCB
_DSC2349

---

### Headers

#### Solder the female headers to the back
_DSC2350

#### Solder the shrouded power header to the front
_DSC2351

#### Solder the I²C header to the front
_DSC2352

[Skiff Friendly Option](skiff_friendly_instructions.md#step-1)

#### Push the female Pico headers onto the Pico itself
_DSC2355

#### Press this new assembly onto the footprint on the PCB
_DSC2356

#### Solder the female headers from the back
_DSC2357

#### Remove the Pico from the female headers
_DSC2358
_DSC2359

---

### Large Capacitors

#### Solder the 10uF capacitors to the front (C15, C16), taking care of the polarity. The white stripe on the capacitor lines up with the stripe on the PCB
_DSC2360

---

### 7805

[Skiff Friendly Option](skiff_friendly_instructions.md#step-2)

#### Solder the 7805 power regulator to the front, with the metal side in line with the white stripe on the PCB

_DSC2361

---

## Jack PCB

The 'Jack PCB' is the remaining board, with the outlines for the front panel components.
The 'front' of the Jack PCB is the side with the OLED, jack, and button outlines, and the 'back' is the side with the OLED configuration diagram.

|Front|Back|
|-----|----|
|||

#### Required Components for Jack PCB
|Component|Quantity|
|---|---|
|1k Resistor|8|
|4.7k Resistor|6|
|100nF Capacitor|2|
|LED|6|
|4x2 Male Header|2|
|Jumper Wire (discarded resistor legs)|4|
|Push Button|2|
|Potentiometer|2|
|Thonkiconn 3.5mm Mono Jack|8|
|OLED Display|1|

---

### Resistors

#### Solder the 1k resistors to the back (R7, R8, R9, R10, R11, R12, R19, R20)
_DSC2362 5

---

#### Solder the 4.7k resistors to the back (R13, R14, R15, R16, R17, R18)
_DSC2362

---

### Small Capacitors

#### Solder the 100nF capacitors to the back (C7, C8). If your board has a polarity marking, ignore it unless you are deliberately using larger polarised capacitors than the BOM calls for, in which case make sure they line up with the PCB marking
_DSC2363

---

### Headers

#### Push the male headers into the female headers that you soldered to the Pico PCB
_DSC2364

#### Push the Jack PCB onto the other side of the male headers
_DSC2365

#### Solder the male headers to the Jack PCB
_DSC2366

#### Pull the two PCBs apart carefully to reveal the perfectly aligned male headers on the Jack PCB
_DSC2367

---

#### OLED Configuration
There are two pin configurations that the OLED used in this build commonly comes in, which are labelled on the board 'TPH' (The Pi Hut), and 'CPC' (CPC, AliExpress, most other suppliers).
The Pi Hut display is preferable as it does not have pre-soldered headers, so is easier to mount on the board. However the CPC display is still entirely usable.

This configuration setup allows you to tell the module which display you are using, as their pins are ordered differently:
TPH: VCC, GND, SDA, SCL
CPC: SDA, SCL, VCC, GND

Don't ask me why there is still not a standard for I²C pin layout in the year 2024, but here we are. Here is how to configure your EuroPi to work with whichever layout you are using:

#### Snip some resistor legs and bend them over the end of something small and round, such as needle-nose pliers
_DSC2410

#### Push the snipped legs into the holes on the PCB according to the diagram and which OLED you have, and then solder either from the top or the bottom
_DSC2411

---

### Front Panel Components

#### Solder the push buttons to the front (SW1, SW2)
_DSC2370

#### Solder the OLED Display to the front
This is quite an awkward operation as the distance the headers need to occupy is not standard to the lengths that 2.54mm headers come in. If you are using a CPC display, your headers are probably pre-soldered, in which case you need to prop the display up somehow while you solder one pin, then go on to solder the rest once you're sure it's straight.

If your display is CPC, the pins will be flush with the PCB if it's at the correct height, which is difficult but possible to solder.

If your display is TPH, you can either solder pins and do it the same way as the CPC method, or use extra-long pin headers instead which will make the soldering process easier, as they will protrude far enough to get a better solder joint.

_DSC2375

#### Place the potentiometers (VR1, VR2) onto the front but don't solder yet
_DSC2376

#### Place the jacks (J1, J2, J3, J4, J5, J6, J7, J8) onto the front but don't solder yet
_DSC2377

#### Place the LEDs (LED1, LED2, LED3, LED4, LED5, LED6) onto the front but don't solder yet, lining up the short leg with the white stripe on the PCB
_DSC2378

#### Push the front panel onto the components, lining up the LEDs so they are flush
_DSC2379

#### Place an elastic band or hair bobble around the PCB and panel to hold them together. I used the plastic coated wire that came with my USB cable
_DSC2380

#### Solder all the components from the back. For the potentiometers, only solder the large lugs on the sides if yours are trimmer type potentiometers. Do not solder the lugs if the potentiometers came with nuts.
_DSC2381

---

## Finish off the assembly

#### Screw the PCB standoff onto the Jack PCB so that the standoff is on the back and the screw on the front
_DSC2383

#### Push the two PCBs together, keeping them both straight to avoid bending the header pins
_DSC2384

#### Screw the second screw into the PCB standoff through front of the Pico PCB to hold the two PCBs together firmly
Don't over-tighten so hard that you damage the PCB, but you also don't want this to rattle loose so make sure it is secure.
_DSC2385

#### Push the Pico into its slot on the Pico PCB
_DSC2387

#### If not done already, peel the protective film off the OLED display
_DSC2389

#### Screw all of the nuts on to hold the components to the front panel.
If your potentiometer came with nuts, use them, otherwise just screw on the jacks.
Also pop on the knobs.
_DSC2390

#### Finally, pop the TL074 and MCP6002 Op-Amps into their respective sockets, making sure the notch in the IC matches the notch on the socket
_DSC2391

---

### (Optional) Multimeter Tests
Use your multimeter set to continuity mode for these tests.

#### Check that there is no continuity between +12V and -12V, between +12V and Ground, and between -12V and Ground on the power header
_DSC2395

If there is continuity on any checks where there shouldn't be then make sure your solder joints are good and that there is no dirt or stray solder bridging any connections. Also make sure that your diodes and power cable are all the correct orientation.

---

### Smoke Test

#### Connect your module to your Eurorack power supply without any other modules connected
_DSC2396

Make sure the cable is connected so that the 'key' on the cable slots into the notch on the header, and the red stripe is on the bottom side of the module.
Turn on your power supply and check for any smoke or discolouration of the PCB around the power connector, and immediately unplug if either occur.
If all is groovy, the congratulations, you've finished building your EuroPi!

---

## Admire your handiwork!

_DSC2397

#### If you have any issues with the build process or programming that are not covered in the [troubleshooting guide](/troubleshooting.md) then please drop us an email at [contact@allensynthesis.co.uk](mailto:contact@allensynthesis.com)

#### Share photos of your build with us on [Instagram](https://www.instagram.com/allensynthesis/), or [email us](mailto:contact@allensynthesis.com)!

#### Now just follow the [programming instructions](/software/programming_instructions.md) to get ready to use your new EuroPi!

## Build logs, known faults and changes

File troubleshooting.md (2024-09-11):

# Troubleshooting the EuroPi module

This document should help you fix any problems you might be having with the hardware or software of the module.
If you have any other issues that aren't covered in this document, please create an Issue on this GitHub repository using the template.
You can search through this file for the error message you are getting or just press Ctrl-F and paste the first line of the message given in Thonny.

## No inputs or outputs are working

#### Steps to fix
1. Make sure your module is connected to both USB for programming and rack power for ±12V supply
2. Make sure the Pico and Jack PCBs are firmly pressed together, and held by the standoff

## Couldn't find the device automatically

```diff
- Couldn't find the device automatically.
- Check the connection (making sure the device is not in bootloader mode) or choose
- "Configure interpreter" in the interpreter menu (bottom-right corner of the window)
- to select specific port or another interpreter.
```

This means that your device is either not connected, or not being detected.
#### Steps to fix
1. Make sure the USB cable is connected firmly to both the Pico and your computer
2. Make sure your USB cable is capable of data transfer rather than just power
3. Re-flash the firmware by following the process set out in the [programming instructions](/software/programming_instructions.md)
4. Re-flash the firmware using the 'flash_nuke.uf2' found on the [Adafruit website](https://learn.adafruit.com/getting-started-with-raspberry-pi-pico-circuitpython/circuitpython), and then re-flash it again using the most recent firmware

## Calibration gets stuck on 10V

This means that the value the module recorded for 10V when you were sending in voltages to the analogue input cannot be reached by the CV output.
This could mean either:
1. The value you sent in for 10V was more than 10V
2. The module actually cannot reach 10V

To test if it is 1 or 2, first retry calibration, making sure the voltages you send in are accurate (never more than 10V). Measure this with a multimeter if you can to be sure.

If this doesn't fix the issue, then you know that your module cannot reach 10V on its own. There are a few things this could be:
1. The LEDs you used draw more current than the standard ones in the BOM, and are thus causing the output voltage to drop below 10V
2. There is a bridge/missing solder joint which is causing the output stage to have a lower gain factor than it should, and thus can't reach 10V
3. (Very unlikely) The output jack is broken and is not connected to the circuit properly

The easiest way to test a few of these possibilities at once is to set the output to the highest value possible, with this code:
```
from europi import *
cv1._set_duty(65535)
```
Simply create a new file with only this code in it, and then run the code with the module connected.
Now, use a multimeter to measure the voltage at the end of a mono cable plugged into the jack, and see if it is above 10V. As long as it is over 10V, even if only by about 0.5V, then this proves that the problem is not any of the above. If this is the case (the voltage is above 10V) then reflash the firmware using the instructions at the bottom of [the steps to fix above](#steps-to-fix-1).

If it was less than 10V, then check all of the solder joints on both PCBs, but especially all of the ones around the TL074 op-amps. If you see any joint that looks like it could be either bridging two pins or cracked, then clean up the joint with some solder braid or a solder sucker (a braid is preferred as it's less likely to damage the board) and re-solder.

If none of this solves the issue, then please post in the support channel of the [Discord server](https://discord.gg/JaQwtCnBV5) with photos of your PCBs, and we can see if we can spot anything!

## EuroPi Hardware Error

```diff
- EuroPi Hardware Error:
- Make sure the OLED display is connected correctly
```

This means that the Pico cannot detect the OLED display.
#### Steps to fix
1. Make sure that the solder joints between the OLED board and the PCB are secure and free of dirt
2. If you have a multimeter, test the continuity of each pin with the appropriate pin on the Pico according to [the pinout](hardware/EuroPi/europi_pinout.pdf)
3. Make sure your PCB standoffs are screwed on tightly; if the two board slip apart by any more than a millimetre or two then the connection will not be made
4. Make sure your OLED matches one of the two compatible pin configurations as outlined in the [build guide](hardware/EuroPi/build_guide.md#oled-configuration)

## Backend terminated or disconnected

```diff
- Backend terminated or disconnected. Use 'Stop/Restart' to restart.
```

The module has become disconnected from your computer.
#### Steps to fix
1. Try pressing Stop/Restart
2. Follow the steps to fix for 'EuroPi Hardware Error'

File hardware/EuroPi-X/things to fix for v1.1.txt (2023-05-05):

add 100k resistor for input_detect pin to prevent chance of sinking too much current while within the 0-3.3v range in edge cases (e.g. input is connected directly to ground, during plugging in process the switched pin and thus the input detect gpio will be connected directly to ground, potentially sinking more current than the rp2040's limit if the input_detect pin is currently transmitting

renumber components to maintain consistency with rp2040 hardware design guide

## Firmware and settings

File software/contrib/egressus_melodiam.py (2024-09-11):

from europi import *
import machine
from time import ticks_diff, ticks_ms
from random import uniform
from europi_script import EuroPiScript
from europi_config import EuroPiConfig
import gc
import math
import framebuf

"""
Egressus Melodiam (Stepped Melody)
author: Nik Ansell (github.com/gamecat69)
date: 19-Feb-24
labels: clocked lfo, sequencer, CV, randomness

Known Issues:
- When the clock rate or output division changes significantly this creates temporary wave shape discontinuities
- Input clocks > 150BPM can cause waveshape glitches. Workaround this by dividing the clock first if working at 150BPM or higher.
- Some input clocks < 16ms can be occasionally missed causing glitchy waves to he output or CV pattern steps to be missed.
Workaround this issue using longer clock pulse durations or 50% duty cycle square waves.
- Performance is affected when using the controls - the poor pico has trouble keeping up with the not-yet optimized code

Possible future work:

- Med [UX]: When in unclocked mode the pattern length cannot be changed - change UI? Or maybe restrict pattern length to 1 (LFO mode only in unclocked mode?)
- Low [FEATURE]: Find a use for ain? Change unClocked clock time?
- High [PERF]: See if performance can be optimized to work with clock inputs < 16ms

Programming notes:

Outputs -> CVPattern Banks -> CV Patterns data structure:

self.cvPatternBanks[idx][self.CvPattern][step]

cvPatternBank[idx] - Output: Each list item is a reference to an output
    [maxCvPatterns] - Cv Pattern Banks: Each list item is a reference to a CV Pattern
        [maxStepLength] - Cv Patterns: Each list item is a CV value per clock step

Slew / interpolation generator structures:

CV shapes are created using interpolation formulas that fill in the gaps between CV step values in a CV pattern.
Each interpolation formula is generated by an associated slew shape function.
There are both linear and non-linear interpolation functions that create various smooth and no-so-smooth shapes.

Each slew shape function generates an array of values (samples) between two given points.
Samples are output on the CV outputs based on the list of pre-computed interpolated values (sample buffers)
A value from the sample buffer is retrieved using a Python generator function (self.slewGenerator()).
One instance of the generator function for each each slew shape exists in a list: self.slewGeneratorObjects[]

A new sample buffer (array of interpolated values) is created at each clock step.
The number of samples required in each sample buffer (one for each output) is calculated at each clock step or if
the clock rate or output division changes.

The timing and associated hanlding of input clock interrupts (clocks to din) is not perfect - python/micropython is not
known to be great at sub-second timing!
Therefore, at the end of each clock step the algorithm tunes itself to work around sample buffer overruns or underruns.
If there is a buffer underrun (not enough samples in the buffer), the previous output voltage (sample) is used until the algorithm
catches back up with itself.

slewGeneratorObjects[] contains 6 object (one for each output)
Each slewGeneratorObjects[] object is a reference to a copy of the self.slewGenerator() function.
The self.slewGenerator() function receives a buffer filled with samples and yields one sample each time it is called using next()

In order to maintain the best balance of smooth waves and Rpi pico memory usage, an algorithm is used to vary the
sample rate automatically based on the selected output division.
This causes the sample rate to be at minium when there is a slow clock and high output division.
Conversely, when there is a fast clock and low output division a higher sample rate is used to avoid unwanted steps
often caused by under-samping a wave form.

"""
# Minimum allowed time between incoming 16th note clocks. Smaller values are too fast for poor ole micropython to keep up
MIN_CLOCK_TIME_MS = 50

# Maximum allowed time between incoming 16th note clocks. This is 2 BPM, larger value causes memory issues unless the next two vals are halfed
MAX_CLOCK_TIME_MS = 3750

# Max sample rate and clock divisor to keep required buffer sizes within memory limits
MAX_SAMPLE_RATE = 32
MAX_OUTPUT_DENOMINATOR = 8

MIN_MS_BETWEEN_SAVES = 2000

# Calculate maximum sample buffer size required
SLEW_BUFFER_SIZE_IN_SAMPLES = int(
    (MAX_CLOCK_TIME_MS / 1000) * MAX_SAMPLE_RATE * MAX_OUTPUT_DENOMINATOR
)

# Reduce knob hysteresis using this value - Mutable Instruments style
KNOB_CHANGE_TOLERANCE = 0.999

# Set the maximum CV voltage using a global config value
# Important: Needs firmware v0.12.1 or higher
MAX_CV_VOLTAGE = europi_config.MAX_OUTPUT_VOLTAGE

MAX_STEP_LENGTH = 32

# Diff between incoming clocks are stored in the FiFo buffer and averaged
# Averaging over 5 values seems to deal with wonky clocks quite well
CLOCK_DIFF_BUFFER_LEN = 5

# If the clock rate changes more than this, trigger a recalculation.
# Avoids wonky waves when wonky clocks are used.
MIN_CLOCK_CHANGE_DETECTION_MS = 100

# Slightly quicker way to get integers from boolean values
BOOL_DICT = {False: 0, True: 1}

# Wave shape bit arrays
WAVE_SHAPE_IMGS = [
    bytearray(
        b"\xfe\x10\x82\x10\x82\x10\x82\x10\x82\x10\x82\x10\x82\x10\x82\x10\x82\x10\x82\x10\x82\x10\x83\xf0"
    ),  # stepUpStepDown
    bytearray(
        b"\x00\x00\x06\x00\x05\x00\t\x00\t\x00\x10\x80\x10\x80 @ @@ @ \x80\x10"
    ),  # linspace (tri)
    bytearray(b"0\x00(\x10D\x10D\x10D D\x10\x82 \x82 \x82 \x82 \x81@\x01\xc0"),  # smooth (sine)
    bytearray(
        b"\x04\x00\x04\x00\x06\x00\x06\x00\n\x00\t\x00\t\x00\x10\x80 \x80 @@ \x80\x10"
    ),  # expUpexpDown
    bytearray(
        b'\x0c\x00\x12\x00\x12\x00"\x00"\x00A\x00A\x00@\x80@\x80\x80@\x80 \x80\x10'
    ),  # sharkTooth
    bytearray(
        b"\x04\x00\x05\x00\x04\x80\x08\x80\x08@\x08@\x10 \x10 \x10   @\x10\x80\x00"
    ),  # sharkToothReverse
    bytearray(
        b"\x03\xf0\x0c\x100\x10 \x10@\x10@\x10@\x10\x80\x10\x80\x10\x80\x10\x80\x10\x80\x10"
    ),  # logUpStepDown
    bytearray(
        b"\xff\x80\x80\x80\x80\x80\x80\x80\x80\x80\x80\x80\x80\x80\x80\x80\x80@\x80@\x80 \x80\x10"
    ),  # stepUpExpDown
]


class EgressusMelodiam(EuroPiScript):
    def __init__(self):

        # Initialize variables
        self.newClockToProcess = False
        self.clockStep = 0
        self.stepPerOutput = [0, 0, 0, 0, 0, 0]
        self.nextStepPerOutput = [0, 0, 0, 0, 0, 0]
        self.CvPattern = 0
        self.resetTimeout = MAX_CLOCK_TIME_MS
        self.screenRefreshNeeded = True
        self.showNewPatternIndicator = False
        self.showNewPatternIndicatorClockStep = 0

        self.numCvPatterns = 1  # Leave at 1 due to memory limitations
        self.maxCvPatterns = 1  # Leave at 1 due to memory limitations

        self.slewArray = []
        self.lastClockTime = 0
        self.lastSlewVoltageOutputTime = [0, 0, 0, 0, 0, 0]
        self.slewGeneratorObjects = [
            self.slewGenerator([0]),
            self.slewGenerator([0]),
            self.slewGenerator([0]),
            self.slewGenerator([0]),
            self.slewGenerator([0]),
            self.slewGenerator([0]),
        ]
        self.slewShapes = [
            self.stepUpStepDown,
            self.linspace,
            self.smooth,
            self.expUpexpDown,
            self.sharkTooth,
            self.sharkToothReverse,
            self.logUpStepDown,
            self.stepUpExpDown,
        ]
        self.voltageExtremes = [0, MAX_CV_VOLTAGE]
        self.outputVoltageFlipFlops = [
            True,
            True,
            True,
            True,
            True,
            True,
        ]  # Flipflops between self.VoltageExtremes for LFO mode

        self.selectedOutput = 0
        self.lastK1Reading = 0
        self.currentK1Reading = 0
        self.lastK2Reading = 0
        self.currentK2Reading = 0

        self.running = False
        self.bufferUnderrunCounter = [0, 0, 0, 0, 0, 0]
        self.bufferOverrunSamples = [0, 0, 0, 0, 0, 0]
        self.samplesPerSec = [0, 0, 0, 0, 0, 0]
        self.msBetweenSamples = [0, 0, 0, 0, 0, 0]

        self.unClockedMode = False
        self.lastClockTime = ticks_ms()
        self.lastSaveState = ticks_ms()
        self.pendingSaveState = False
        self.previousOutputVoltage = [0, 0, 0, 0, 0, 0]
        self.slewBufferSampleNum = [0, 0, 0, 0, 0, 0]
        self.slewBufferPosition = [0, 0, 0, 0, 0, 0]
        self.bufferSampleOffsets = [0, 0, 0, 0, 0, 0]
        self.squareOutputs = [0, 0, 0, 0, 0, 0]

        self.loadState()
        # pre-create slew buffers to avoid memory allocation errors
        self.initSlewBuffers()

        # Initialize inputClockDiffs  using previous self.msBetweenClocks from loadState()
        self.inputClockDiffs = []

        # Init clock diff buffer with the default or saved value
        for n in range(CLOCK_DIFF_BUFFER_LEN):
            self.inputClockDiffs.append(self.msBetweenClocks)
        self.averageMsBetweenClocks = self.average(self.inputClockDiffs)

        # Clock rate or output division changed, recalculate optimal sample rate
        self.calculateOptimalSampleRate()

        # -----------------------------
        # Interupt Handling functions
        # -----------------------------

        @din.handler
        def clockTrigger():
            """Triggered on each rising edge into digital input. Sets running flag to true.
            Sets a flag to tell main() to process the clock step. Ignored in unclocked mode."""

            self.running = True

            if not self.unClockedMode:
                self.newClockToProcess = True

        @b1.handler_falling
        def b1Pressed():
            """Triggered when B1 is pressed and released"""
            if (
                ticks_diff(ticks_ms(), b1.last_pressed()) > 2000
                and ticks_diff(ticks_ms(), b1.last_pressed()) < 5000
            ):
                # long press generate new CV pattern
                self.generateNewRandomCVPattern(new=False, activePatternOnly=True)
                self.showNewPatternIndicator = True
                self.screenRefreshNeeded = True
                self.showNewPatternIndicatorClockStep = self.clockStep
                self.pendingSaveState = True
                #self.saveState()
            else:
                # short press change slew mode
                self.outputSlewModes[self.selectedOutput] = (
                    self.outputSlewModes[self.selectedOutput] + 1
                ) % len(self.slewShapes)
                self.screenRefreshNeeded = True
                self.pendingSaveState = True
                #self.saveState()

        @b2.handler_falling
        def b2Pressed():
            """Triggered when B2 is pressed and released"""
            if (
                ticks_diff(ticks_ms(), b2.last_pressed()) > 2000
                and ticks_diff(ticks_ms(), b2.last_pressed()) < 5000
            ):
                # long press change to unclocked mode
                self.unClockedMode = not self.unClockedMode
                if self.unClockedMode:
                    self.running = True
                self.pendingSaveState = True
                #self.saveState()

                # Update previous knob values to avoid them changing when the mode changes
                self.lastK1Reading = self.currentK1Reading
                self.lastK2Reading = self.currentK2Reading
                self.screenRefreshNeeded = True

            else:
                # short press change selected output
                self.selectedOutput = (self.selectedOutput + 1) % 6
                self.screenRefreshNeeded = True
                self.pendingSaveState = True
                #self.saveState()

    def calculateOptimalSampleRate(self):
        """Calculate optimal sample rate for smooth CV output while using minimal memory"""
        for idx in range(len(cvs)):
            self.samplesPerSec[idx] = int(
                min(2 *
                    (MAX_SAMPLE_RATE / self.outputDivisions[idx])
                    * (MAX_CLOCK_TIME_MS / self.averageMsBetweenClocks),
                    MAX_SAMPLE_RATE,
                )
            )
            self.msBetweenSamples[idx] = int(1000 / self.samplesPerSec[idx])

    def initSlewBuffers(self):
        """Create slew buffers and fill with zeros"""
        self.slewBuffers = []
        for n in range(6):  # for each output 0-5
            self.slewBuffers.append([])  # add new empty list to the buffer list
            for m in range(SLEW_BUFFER_SIZE_IN_SAMPLES):
                self.slewBuffers[n].append(0)

    def average(self, list):
        """Pythonic mean average function"""
        myList = list.copy()
        return sum(myList) / len(myList)

    def initCvPatternBanks(self):
        """Initialize CV pattern banks"""
        # Init CV pattern banks, one for each output
        self.cvPatternBanks = [[], [], [], [], [], []]
        for n in range(self.maxCvPatterns):
            self.generateNewRandomCVPattern(self)
        return self.cvPatternBanks

    def generateNewRandomCVPattern(self, new=True, activePatternOnly=False):
        """Generate new CV pattern for existing bank or create a new bank

        @param new  If true, create a new pattern/overwrite the existing one. Otherwise re-use the existing pattern
        @param activePatternOnly  If true, generate pattern for selected output. Otherwise generate pattern for all outputs

        @return True if the pattern(s) were successfully generated, otherwise False
        """
        # Note: This function is capable of working with multiple pattern banks
        #  However, due to current memory limitations only one pattern bank is used
        try:
            gc.collect()
            if new:
                # new flag provided, create new list
                if activePatternOnly:
                    self.cvPatternBanks[self.selectedOutput].append(
                        self.generateRandomPattern(MAX_STEP_LENGTH, 0, MAX_CV_VOLTAGE)
                    )
                else:
                    for pattern in self.cvPatternBanks:
                        pattern.append(
                            self.generateRandomPattern(MAX_STEP_LENGTH, 0, MAX_CV_VOLTAGE)
                        )
            else:
                # Update existing list
                if activePatternOnly:
                    self.cvPatternBanks[self.selectedOutput][self.CvPattern] = (
                        self.generateRandomPattern(MAX_STEP_LENGTH, 0, MAX_CV_VOLTAGE)
                    )
                else:
                    for pattern in self.cvPatternBanks:
                        pattern[self.CvPattern] = self.generateRandomPattern(
                            MAX_STEP_LENGTH, 0, MAX_CV_VOLTAGE
                        )
            return True
        except Exception:
            return False

    def generateRandomPattern(self, length, min, max):
        """Generate a random pattern of a desired length containing values between min and max

        @param length  The length of the desired pattern
        @param min  The minimum value for pattern elements (inclusive)
        @param max  The maximum value for pattern elements (inclusive)

        @return  The generated pattern
        """
        self.t = []
        for i in range(0, length):
            self.t.append(round(uniform(min, max), 3))
        return self.t

    def main(self):
        """Entry point - main loop. See inline comments for more info"""
        while True:
            self.updateScreen()
            self.getK1Value()
            self.getOutputDivision()

            if self.newClockToProcess:

                # Get the time difference since the last clockTime
                newDiffBetweenClocks = min(MAX_CLOCK_TIME_MS, ticks_ms() - self.lastClockTime)
                self.lastClockTime = ticks_ms()

                # Add time diff between clocks to inputClockDiffs Fifo list, skipping the first clock as we have no reference
                if self.clockStep > 0:
                    self.inputClockDiffs[self.clockStep % CLOCK_DIFF_BUFFER_LEN] = (
                        newDiffBetweenClocks
                    )

                # Clock rate change detection
                if (
                    self.clockStep >= CLOCK_DIFF_BUFFER_LEN
                    and abs(newDiffBetweenClocks - self.averageMsBetweenClocks)
                    > MIN_CLOCK_CHANGE_DETECTION_MS
                ):
                    # Update average ms between clocks
                    self.averageMsBetweenClocks = self.average(self.inputClockDiffs)
                    # Clock rate or output division changed, recalculate optimal sample rate
                    self.calculateOptimalSampleRate()

                self.handleClockStep()
                # Incremenent the clock step
                self.clockStep += 1
                self.newClockToProcess = False

            # Cycle through outputs, process when needed
            for idx in range(len(cvs)):
                if (
                    ticks_diff(ticks_ms(), self.lastSlewVoltageOutputTime[idx])
                    >= self.msBetweenSamples[idx]
                    and self.running
                ):

                    try:

                        # Do we have a sample in the buffer?
                        if self.slewBufferPosition[idx] < self.slewBufferSampleNum[idx]:
                            # Yes, we have a sample, output voltage to match the sample, reset underrun counter and advance position in buffer

                            # If a square interpolation mode (0) a precalculated value is used
                            # as the generator function for square waves was really buggy
                            if self.outputSlewModes[idx] == 0:
                                v = self.squareOutputs[idx]
                            else:
                                v = next(self.slewGeneratorObjects[idx])
                            cvs[idx].voltage(v)
                            self.previousOutputVoltage[idx] = v
                            self.bufferUnderrunCounter[idx] = 0
                        else:
                            # We do not have a sample - buffer under run
                            # Output the previous voltage to keep things as smooth as possible
                            cvs[idx].voltage(self.previousOutputVoltage[idx])
                            self.bufferUnderrunCounter[idx] += 1

                        # Advance the position in the sample/slew buffer
                        self.slewBufferPosition[idx] += 1

                        # Update the last sample output time
                        self.lastSlewVoltageOutputTime[idx] = ticks_ms()

                    except StopIteration:
                        continue

            # Save state
            if self.pendingSaveState and ticks_diff(ticks_ms(), self.lastSaveState) >= MIN_MS_BETWEEN_SAVES:
                self.saveState()
                self.pendingSaveState = False

            # If we are not being clocked, trigger a clock after the configured clock time
            if (
                self.unClockedMode
                and ticks_diff(ticks_ms(), self.lastClockTime) >= self.averageMsBetweenClocks
            ):
                self.running = True
                self.lastClockTime = ticks_ms()
                self.handleClockStep()
                self.clockStep += 1

            # If I have been running, then stopped for longer than resetTimeout, reset all steps to 0
            if (
                not self.unClockedMode
                and self.clockStep != 0
                and ticks_diff(ticks_ms(), din.last_triggered()) > self.resetTimeout
            ):
                for idx in range(len(cvs)):
                    self.stepPerOutput[idx] = 0
                # Update screen with the upcoming CV pattern
                self.screenRefreshNeeded = True
                self.pendingSaveState = True
                #self.saveState()
                self.running = False
                for cv in cvs:
                    cv.off()

                self.bufferUnderrunCounter = [0, 0, 0, 0, 0, 0]
                self.bufferOverrunSamples = [0, 0, 0, 0, 0, 0]
                self.slewBufferPosition = [0, 0, 0, 0, 0, 0]
                self.bufferSampleOffsets = [0, 0, 0, 0, 0, 0]

    def handleClockStep(self):
        """Advances step and generates new slew voltages to next value in CV pattern"""

        # Cycle through outputs and generate slew for each
        for idx in range(len(cvs)):

            # If the clockstep is a division of the output division
            if self.clockStep % (self.outputDivisions[idx]) == 0:
                # flip the flip flop value for LFO mode

                self.outputVoltageFlipFlops[idx] = not self.outputVoltageFlipFlops[idx]

                # Catch buffer over-runs by detecting that not all samples were used in the last cycle
                if self.clockStep > CLOCK_DIFF_BUFFER_LEN and not self.unClockedMode:
                    self.bufferOverrunSamples[idx] = int(
                        self.slewBufferPosition[idx] - self.slewBufferSampleNum[idx]
                    )

                    self.bufferSampleOffsets[idx] = (
                        self.bufferSampleOffsets[idx] - self.bufferOverrunSamples[idx]
                    )

                else:
                    self.bufferSampleOffsets[idx] = 0
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

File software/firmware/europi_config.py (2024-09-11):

import configuration
from configuration import ConfigFile, ConfigSpec

# Pico machine CPU freq.
# Default pico CPU freq is 125_000_000 (125mHz)
PICO_DEFAULT_CPU_FREQ = 125_000_000
OVERCLOCKED_CPU_FREQ = 250_000_000


class EuroPiConfig:
    """This class provides EuroPi's global config points.

    To override the default values, create /config/EuroPiConfig.json on the Raspberry Pi Pico
    and populate it with a JSON object. e.g. if your build has the oled mounted upside-down compared
    to normal, the contents of /config/EuroPiConfig.json should look like this:

    {
        "ROTATE_DISPLAY": true
    }
    """

    @classmethod
    def config_points(cls):
        # fmt: off
        return [
            # EuroPi revision -- this is currently unused, but reserved for future expansion
            configuration.choice(
                name="EUROPI_MODEL",
                choices = ["europi"],
                default="europi"
            ),

            # CPU & board settings
            configuration.choice(
                name="PICO_MODEL",
                choices=["pico", "pico w"],
                default="pico"
            ),
            configuration.choice(
                name="CPU_FREQ",
                choices=[PICO_DEFAULT_CPU_FREQ, OVERCLOCKED_CPU_FREQ],
                default=OVERCLOCKED_CPU_FREQ,
            ),

            # Display settings
            configuration.boolean(
                name="ROTATE_DISPLAY",
                default=False
            ),
            configuration.integer(
                name="DISPLAY_WIDTH",
                minimum=8,
                maximum=1024,
                default=128
            ),
            configuration.integer(
                name="DISPLAY_HEIGHT",
                minimum=8,
                maximum=1024,
                default=32
            ),
            configuration.choice(
                name="DISPLAY_SDA",
                choices=[0, 2, 4, 6, 8, 10, 12, 14, 16, 18, 20, 26],
                default=0,
            ),
            configuration.choice(
                name="DISPLAY_SCL",
                choices=[1, 3, 5, 7, 9, 11, 13, 15, 17, 19, 21, 27],
                default=1,
            ),
            configuration.integer(
                name="DISPLAY_CHANNEL",
                minimum=0,
                maximum=1,
                default=0
            ),

            # I/O voltage settings
            configuration.floatingPoint(
                name="MAX_OUTPUT_VOLTAGE",
                minimum=1.0,
                maximum=10.0,
                default=10.0
            ),
            configuration.floatingPoint(
                name="MAX_INPUT_VOLTAGE",
                minimum=1.0,
                maximum=12.0,
                default=12.0
            ),
            configuration.floatingPoint(
                name="GATE_VOLTAGE",
                minimum=1.0,
                maximum=10.0,
                default=5.0
            ),

            # Menu settings
            configuration.boolean(
                name="MENU_AFTER_POWER_ON",
                default=False
            ),
        ]
        # fmt: on


def load_europi_config():
    return ConfigFile.load_config(EuroPiConfig, ConfigSpec(EuroPiConfig.config_points()))

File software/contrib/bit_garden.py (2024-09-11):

try:
    # Local development
    from software.firmware import europi_config
    from software.firmware.europi import CHAR_HEIGHT, CHAR_WIDTH, OLED_WIDTH
    from software.firmware.europi import ain, din, k1, k2, oled, b1, b2, cvs
    from software.firmware.europi_script import EuroPiScript
    from software.firmware.experimental.a_to_d import AnalogReaderDigitalWrapper
    from software.firmware.experimental.custom_font import CustomFontDisplay
    from software.firmware.experimental.fonts import ubuntumono20

except ImportError:
    # Device import path
    from europi import *
    from europi_script import EuroPiScript
    from experimental.a_to_d import AnalogReaderDigitalWrapper
    from experimental.custom_font import CustomFontDisplay
    from experimental.fonts import ubuntumono20

from random import random, seed, randint
from time import sleep_ms, ticks_diff, ticks_ms

DEFAULT_SEQUENCE_LENGTH = 16
DEFAULT_SEED = 0x8F26
DEFAULT_PROBABILITIES = [0.92, 0.86, 0.64, 0.48, 0.32, 0.18]
MAX_STEPS = 32
LONG_PRESS_MS = 500

# Use the Custom Font wrapper for oled display.
oled = CustomFontDisplay()


class TriggerMode:
    TRIGGER = 1
    GATE = 2
    FLIP = 3


class Page:
    MAIN = 1
    EDIT_PROBABILITY = 2
    EDIT_SEED = 3


class Output:
    def __init__(self, cv, probability):
        self.cv = cv
        self.probability = probability
        self.pattern = [0] * MAX_STEPS
        self.build_pattern()

    def build_pattern(self):
        for i in range(MAX_STEPS):
            self.pattern[i] = random() < self.probability

    def trigger(self, step, mode):
        """Input trigger has gone high. Change the cv state based on mode for given step."""
        # If random is greater than the probability range, return without triggering.
        if not self.pattern[step]:
            return

        if mode == TriggerMode.FLIP:
            self.cv.toggle()
        else:
            self.cv.on()

    def trigger_off(self):
        """Input trigger has gone low. Turn off when in 'trigger' mode."""
        self.cv.off()


class SeedPacket:
    def __init__(self, seed, outputs, probabilities, mode):
        self.seed = seed
        self.mode = mode
        self.outputs = []
        for cv, prob in zip(outputs, probabilities):
            self.outputs.append(Output(cv, prob))

    def new_seed(self):
        """Seed the pseudo-random number generator with a new random seed and generate new patterns."""
        self.seed = randint(0,0xFFFF)
        seed(self.seed)
        for out in self.outputs:
            out.build_pattern()
        return self.seed

    def trigger(self, step):
        """Input trigger has gone high."""
        if self.mode == TriggerMode.GATE:
            for out in self.outputs:
                out.trigger_off()
            # Brief low period between gates.
            sleep_ms(5)

        for out in self.outputs:
            out.trigger(step, self.mode)

    def trigger_off(self):
        """Input trigger has gone low."""
        if self.mode != TriggerMode.TRIGGER:
            return

        for out in self.outputs:
            out.trigger_off()

    @property
    def probabilities(self):
        """Return the list of output probability between 0 and 1."""
        return [out.probability for out in self.outputs]

    def update_probability(self, index, prob):
        """Update the probability and pattern for the given output."""
        self.outputs[index].probability = prob
        self.outputs[index].build_pattern()


class BitGarden(EuroPiScript):
    def __init__(self):
        super().__init__()
        # Default initial state
        self.state = {
            "sequence_length": DEFAULT_SEQUENCE_LENGTH,
            "seed": DEFAULT_SEED,
            "mode": TriggerMode.TRIGGER,
            "probabilities": DEFAULT_PROBABILITIES,
        }
        self.state.update(self.load_state_json())

        # Class state variables
        self.step_counter = 0
        self.sequence_length = self.state["sequence_length"]
        self.packet = SeedPacket(self.state["seed"], cvs, self.state["probabilities"], self.state["mode"])
        self.pattern_index = 0

        # Private class instance variables
        self._page = Page.MAIN
        self._update_display = True
        self._prev_k1 = None
        self._prev_k2 = None
        self._seed_index = 0
        self._prob_index = 0

        # Attach IRQ Handlers
        din.handler(self.digital_rising)
        din.handler_falling(self.digital_falling)
        b1.handler_falling(self.b1_handler)
        b2.handler_falling(self.b2_handler)
        self.din2 = AnalogReaderDigitalWrapper(ain, cb_rising=self.digital2_rising)


    @classmethod
    def display_name(cls):
        return "Bit Garden"

    def save_state(self):
        """Save the current state variables as JSON."""
        self.state.update({
            "sequence_length": self.sequence_length,
            "seed": self.packet.seed,
            "mode": self.packet.mode,
            "probabilities": self.packet.probabilities,
        })
        self.save_state_json(self.state)

    def digital_rising(self):
        """Advance the pseudo-random sequence step counter."""
        self.step_counter = (self.step_counter + 1) % self.sequence_length
        self.packet.trigger(self.step_counter)
        self._update_display = True

    def digital_falling(self):
        """Tell the SeedPacket the digital input has gone low for Trigger mode."""
        self.packet.trigger_off()
    
    def digital2_rising(self):
        self.packet.new_seed()
        self._update_display = True

    def b1_handler(self):
        self._update_display = True

        # Short press  to toggle modde, long press to switch to edit probability page.
        if self._page == Page.MAIN:
            if ticks_diff(ticks_ms(), b1.last_pressed()) < LONG_PRESS_MS:
                self.toggle_mode()
            else:
                self._prev_k2 = None
                self._page = Page.EDIT_PROBABILITY

        # If on Edit Probability page, b1 press will return home.
        elif self._page == Page.EDIT_PROBABILITY:
            self._prob_index = (self._prob_index + 1) % 6

        # Change seed edit index.
        elif self._page == Page.EDIT_SEED:
            self._seed_index = (self._seed_index + 1) % 4

    def b2_handler(self):
        self._update_display = True

        if self._page == Page.MAIN:
            # Short press vs Long press
            if ticks_diff(ticks_ms(), b2.last_pressed()) < LONG_PRESS_MS:
                self.new_seed()
            else:
                self._temp_seed = self.packet.seed
                self._prev_k2 = None
                self._page = Page.EDIT_SEED

        elif self._page == Page.EDIT_PROBABILITY:
            self._page = Page.MAIN

        elif self._page == Page.EDIT_SEED:
            # If on Edit Seed page, b2 press will return home.
            self.packet.seed = self._temp_seed
            self._page = Page.MAIN
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

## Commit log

2023-05-01 create bare classes for adc input
2023-05-05 make breadboard compatible
    also adjust thermal spoke count in design rules to remove errors (only 1 spoke required)
    [EuroPi-X.kicad_pcb]
2023-05-05 add led on gp25
    [EuroPi-X.kicad_sch]
2023-05-05 add led to pcb
    [EuroPi-X.kicad_pcb]
2024-01-15 create neopixel dev board
    [bom.csv, designators.csv, neopixels.kicad_pcb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]
2024-01-15 kicad save
    [bom.csv, designators.csv, neopixels.kicad_pcb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]
2024-01-15 create analogue input dev board
    [analogue_input.kicad_pcb, analogue_input.kicad_sch]
2024-01-15 finish pcb
    [analogue_input.kicad_pcb]
2024-01-15 add input detect pin
    [analogue_input.kicad_pcb, analogue_input.kicad_sch]
2024-01-15 rearrange pins
    rearrange pins so that i2c matches europi to be able to be used as expander
    [analogue_input.kicad_pcb, analogue_input.kicad_sch]
2024-01-15 rearrange for 1u
    make pcb able to fit in 1u format
    [analogue_input.kicad_pcb]
2024-01-15 add panel
    realised that it's not fitted into 1u yet as the pcb was offset by -3mm on the Y axis
    needs reworking again to actually fit, plus making the panel
    [analogue_input.kicad_pcb]
2024-01-15 create analogue switch dev board
    [analogue_switches.kicad_pcb, analogue_switches.kicad_sch, bom.csv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]
2024-01-15 move dev boards to dev folder
    [analogue_input.kicad_pcb, analogue_input.kicad_sch, bom.csv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]
2024-01-15 rearrange for 1u
    [analogue_input.kicad_pcb]
2024-01-16 add panel
    [analogue_input.kicad_pcb]
2024-01-16 generate jlc files
    [analogue_input.kicad_pcb, bom.csv, designators.csv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]
2024-01-16 add ground plane to panel
    [analogue_input.kicad_pcb, bom.csv, designators.csv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]
2024-01-16 rearrange fully
    [analogue_input.kicad_pcb, analogue_input.kicad_sch]
2024-01-16 add 3d models
    [analogue_input.kicad_pcb]
2024-01-16 rearrange neopixel dev board
    make neopixel dev board 1u
    [analogue_input.kicad_pcb, neopixels.kicad_pcb]
2024-01-29 create output dev board
    [EuroPi-X.kicad_sch, output stage.kicad_pcb, output stage.kicad_sch]
2024-01-29 save output stage
    [bom.csv, designators.csv, output stage.kicad_pcb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]
2024-01-29 fix pad shape
    [output stage.kicad_pcb]
2024-01-31 analogue input dev board update
    [analogue_input.kicad_pcb, analogue_input.kicad_sch]
2025-11-25 create kicad project
    [europi_schematic.kicad_pcb, europi_schematic.kicad_sch]
2025-12-01 rough layout
    [europi_schematic.kicad_pcb, europi_schematic.kicad_sch]
2025-12-02 passes drc
    [europi_schematic.kicad_pcb, europi_schematic.kicad_sch]
2025-12-02 ordered rev 1
    [europi_schematic.kicad_pcb, europi_schematic.kicad_sch]
2025-12-02 move files out of containing directory;
    [OLED_Stand.stl, OLED_Stand_Pi_Hut.stl, bom.csv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]
2025-12-02 reorganise hardware and add new readme
    [europi-surface-mount.kicad_pcb, europi-surface-mount.kicad_sch]
